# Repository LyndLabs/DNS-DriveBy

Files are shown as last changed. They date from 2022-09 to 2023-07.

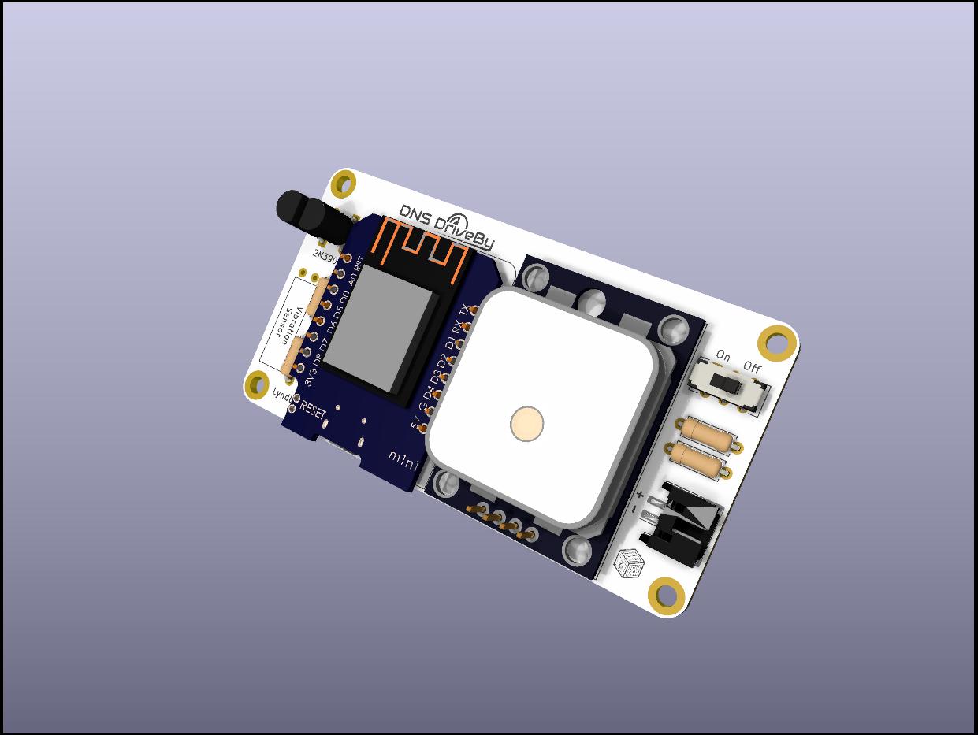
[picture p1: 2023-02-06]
images/DNS-DriveBy-Render.jpg

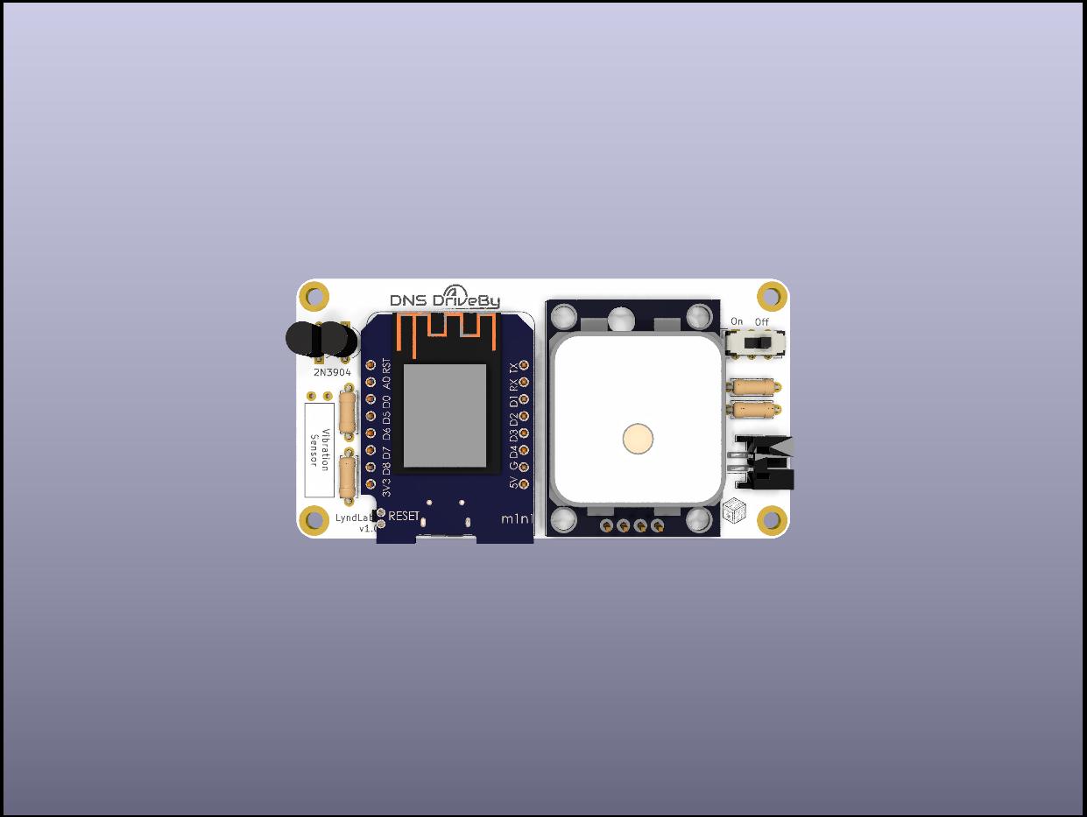
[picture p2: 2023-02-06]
images/DNS-DriveBy-Render-2.jpg

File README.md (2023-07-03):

<p align="center">

</p>

## What is DNS DriveBy?     
DNS-Driveby is a $10 tracker that uses Open Wi-Fi networks for telemetry & reconaissance, instead of a SIM card.  It logs GPS coordinates & other data to its internal memory, scans for un-authenticated Wi-Fi networks, and uses DNS Exfiltration through [DNS CanaryTokens](https://canarytokens.org) to bypass captive portals!  Read about how I created it on [Hackster](https://www.hackster.io/alexlynd/dns-driveby-stealthy-gps-tracking-using-open-wi-fi-65730a)!

## Resources
- Stealthy GPS Tracking Using Open Wi-Fi - [Hackster](https://www.hackster.io/alexlynd/dns-driveby-stealthy-gps-tracking-using-open-wi-fi-65730a)
- Using DNS DriveBy as a GPS Tracker - [Hak5](https://youtu.be/H0Nwff0KDJ0?t=151)

## Build Instructions
[Assembly Guide](https://dnsdriveby.com/guides/get-started/assembly/)

## Changelog v1.2
- MicroSD Card Support
- JST Switch connector?
- Route LiPo under board
- SH1106 / SSD1306 Add-On

## To-Do
- Fix GPS Traces
- Larger Resistor Footprint
- Improved BMS

- Screen Support
- Build Custom Binary
- OTA Update via Web Interface

## Documented Issues (Note to Self / Future Docs)
- Arduino-CLI VSCode Plugin doesn't support SPIFFS build

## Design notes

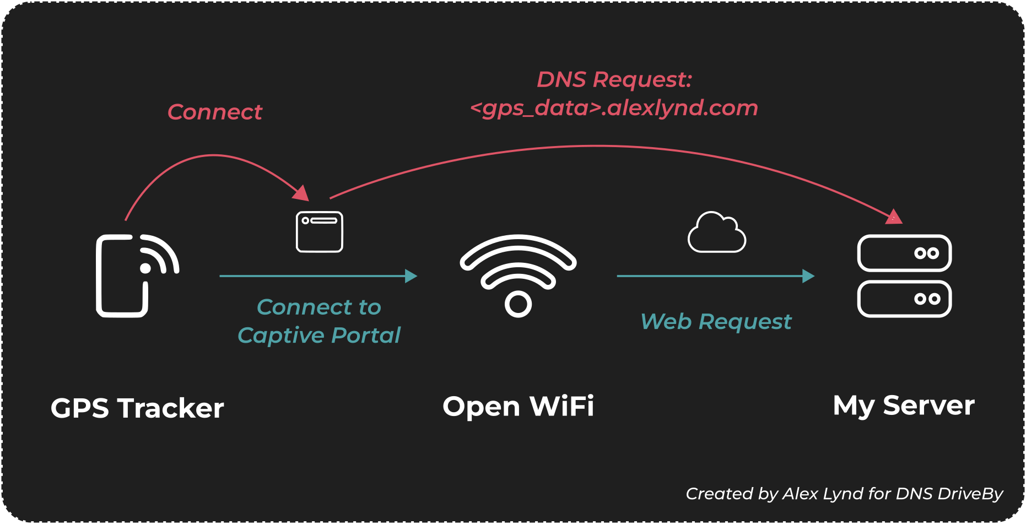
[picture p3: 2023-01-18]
images/dns-exfil-model.png

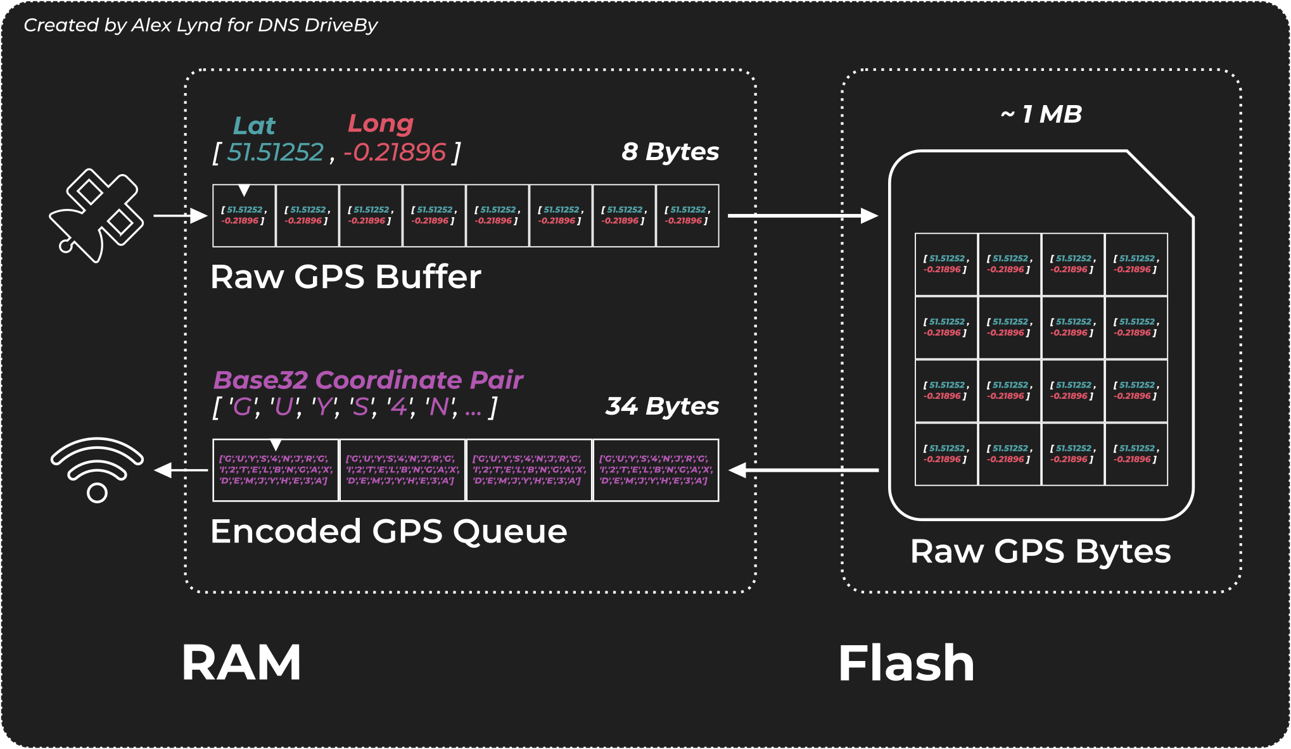
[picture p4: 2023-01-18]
images/memory-model.png

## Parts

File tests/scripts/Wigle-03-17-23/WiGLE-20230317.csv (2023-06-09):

WigleWifi-1.4 | appRelease=2.x | model=SERVER | release=2.50 | device=WiGLE SERVER | display=NONE | brand=WiGLE.net
MAC | SSID | AuthMode | FirstSeen | Channel | RSSI | CurrentLatitude | CurrentLongitude | AltitudeMeters | AccuracyMeters | Type
00:01:21:20:0B:40 |  | [WPA2-PSK-CCMP] | 2023-03-17 17:50:40 | -1 | -88 | 33.85910797 | -118.01226807 | -17 | 3.216 | WIFI
00:01:21:20:0B:41 | BBD Public | [WPA2-PSK-CCMP] | 2023-03-17 17:50:40 | -1 | -88 | 33.85910797 | -118.01226807 | -17 | 3.216 | WIFI
00:01:21:20:0B:42 | BBD Private | [WPA2-PSK-CCMP] | 2023-03-17 17:50:40 | -1 | -88 | 33.85910797 | -118.01226807 | -17 | 3.216 | WIFI
00:01:21:6D:9A:F0 |  | [WPA2-PSK-CCMP] | 2023-03-17 17:50:40 | -1 | -87 | 33.85910797 | -118.01226807 | -17 | 3.216 | WIFI
00:01:21:6D:9A:F1 | BBD Public | [WPA2-PSK-CCMP] | 2023-03-17 17:50:40 | -1 | -89 | 33.85910797 | -118.01226807 | -17 | 3.216 | WIFI
00:01:21:6D:9A:F2 | BBD Private | [WPA2-PSK-CCMP] | 2023-03-17 17:50:40 | -1 | -89 | 33.85910797 | -118.01226807 | -17 | 3.216 | WIFI
00:04:F3:1A:96:80 | xbee-0004F31A9680 | [WPA2-PSK-CCMP] | 2023-03-17 17:05:41 | -1 | -79 | 33.88780975 | -118.02951813 | -8 | 4.288 | WIFI
00:0A:99:8B:1F:3F | 336645 | [WPA-PSK-CCMP] | 2023-03-17 17:25:41 | -1 | -80 | 33.87351608 | -118.02902985 | -2 | 9.648 | WIFI
00:0D:97:01:14:AB | Standalone | [] | 2023-03-17 17:27:41 | -1 | -76 | 33.87284088 | -118.02864838 | -6 | 3.216 | WIFI
00:0E:3B:2C:6A:60 | Vaado | [WPA-PSK-CCMP] | 2023-03-17 17:56:12 | -1 | -81 | 33.85915756 | -118.0036087 | -26 | 9.648 | WIFI
00:11:32:E3:EC:1D | EKO | [WPA2-PSK-CCMP] | 2023-03-17 15:54:34 | -1 | -83 | 33.86017609 | -117.99799347 | 8 | 3.216 | WIFI
00:11:32:E7:2F:D0 | EKO | [WPA2-PSK-CCMP] | 2023-03-17 15:54:34 | -1 | -76 | 33.86017609 | -117.99799347 | 8 | 5.36 | WIFI
00:11:32:E7:37:CD | EKO | [WPA2-PSK-CCMP] | 2023-03-17 15:54:34 | -1 | -87 | 33.86017609 | -117.99799347 | 8 | 5.36 | WIFI
00:11:74:ED:C6:E0 |  | [WPA2-PSK-CCMP] | 2023-03-17 16:04:40 | -1 | -85 | 33.86976242 | -117.99803162 | -5 | 3.216 | WIFI
00:11:74:ED:C6:E1 |  | [WPA2-PSK-CCMP] | 2023-03-17 16:04:40 | -1 | -84 | 33.86976242 | -117.99803162 | -5 | 3.216 | WIFI
00:11:74:ED:C6:F0 |  | [WPA2-PSK-CCMP] | 2023-03-17 16:05:10 | -1 | -75 | 33.87014008 | -117.99806213 | -7 | 3.216 | WIFI
00:11:74:ED:C6:F1 |  | [WPA2-PSK-CCMP] | 2023-03-17 16:05:10 | -1 | -75 | 33.87014008 | -117.99806213 | -7 | 3.216 | WIFI
00:18:0A:23:FC:A4 | Ken Grody Ford- Guest | [WPA2-PSK-CCMP] | 2023-03-17 16:04:10 | -1 | -77 | 33.86975861 | -117.99802399 | -6 | 3.216 | WIFI
00:18:0A:F0:5A:C0 | OM | [WPA2-PSK-CCMP] | 2023-03-17 17:24:41 | -1 | -81 | 33.873806 | -118.02893829 | -2 | 9.648 | WIFI
00:18:0A:F1:74:50 | RFInternal | [WPA2-PSK-CCMP] | 2023-03-17 17:19:41 | -1 | -83 | 33.87769318 | -118.02895355 | -6 | 10.72 | WIFI
00:1E:F7:54:24:D3 | vendor_wifi | [WPA2-PSK-CCMP] | 2023-03-17 17:33:41 | -1 | -80 | 33.8686676 | -118.02858734 | -15 | 9.648 | WIFI
00:1F:26:2B:DA:20 |  | [WPA2-PSK-CCMP] | 2023-03-17 17:33:41 | -1 | -89 | 33.8686676 | -118.02858734 | -15 | 9.648 | WIFI
00:1F:26:2B:FC:40 |  | [WPA2-PSK-CCMP] | 2023-03-17 17:33:41 | -1 | -89 | 33.8686676 | -118.02858734 | -15 | 9.648 | WIFI
00:1F:26:2B:FC:43 | vendor_wifi | [WPA2-PSK-CCMP] | 2023-03-17 17:33:41 | -1 | -87 | 33.8686676 | -118.02858734 | -15 | 9.648 | WIFI
00:1F:26:2B:FC:49 |  | [WEP] | 2023-03-17 17:33:41 | -1 | -89 | 33.8686676 | -118.02858734 | -15 | 9.648 | WIFI
00:22:3B:0D:7B:B5 | Netwave-1 | [WPA2-PSK-CCMP] | 2023-03-17 16:15:10 | -1 | -87 | 33.87334061 | -118.00759125 | -7 | 3.216 | WIFI
00:25:CA:29:8D:8B | sdp5g | [WPA2-PSK-CCMP] | 2023-03-17 17:03:11 | -1 | -83 | 33.88780975 | -118.02951813 | -8 | 3.216 | WIFI
00:25:CA:6A:2C:F1 | KeepTruckin Hotspot - HB493614 | [WPA2-PSK-CCMP] | 2023-03-17 17:15:41 | -1 | -78 | 33.88343811 | -118.02910614 | 6 | 9.648 | WIFI
00:25:CA:6D:9B:7B | KeepTruckin Hotspot - HB514740 | [WPA2-PSK-CCMP] | 2023-03-17 17:36:41 | -1 | -85 | 33.8663826 | -118.02852631 | -16 | 9.648 | WIFI
00:30:44:2E:20:FD |  | [WPA2-PSK-CCMP] | 2023-03-17 16:04:10 | -1 | -79 | 33.86975861 | -117.99802399 | -6 | 3.216 | WIFI
00:30:44:62:91:D7 | KIMSBY HOUSE 2G | [WPA2-PSK-CCMP] | 2023-03-17 17:01:41 | -1 | -90 | 33.88779831 | -118.02951813 | -6 | 3.216 | WIFI
00:31:92:DA:F1:16 | TP-Link_F117 | [WPA2-PSK-CCMP] | 2023-03-17 17:31:41 | -1 | -88 | 33.87091064 | -118.02863312 | -11 | 3.216 | WIFI
00:31:92:DA:F1:17 | TP-Link_F117 | [WPA2-PSK-CCMP] | 2023-03-17 17:30:41 | -1 | -81 | 33.87123871 | -118.02864075 | -11 | 9.648 | WIFI
00:54:AF:14:75:8B | Hotspot758B | [WPA2-PSK-CCMP] | 2023-03-17 17:10:41 | -1 | -82 | 33.88757706 | -118.02933502 | -8 | 3.216 | WIFI
00:54:AF:1B:D0:05 | HotspotD005 | [WPA2-PSK-CCMP] | 2023-03-17 16:03:40 | -1 | -72 | 33.86941147 | -117.99812317 | 2 | 10.72 | WIFI
00:54:AF:27:BF:8D | HotspotBF8D | [WPA2-PSK-CCMP] | 2023-03-17 17:13:41 | -1 | -66 | 33.88420486 | -118.0291214 | 9 | 4.288 | WIFI
00:54:AF:2F:3F:3E | Hotspot3F3E | [WPA2-PSK-CCMP] | 2023-03-17 15:46:38 | -1 | -70 | 33.85936356 | -117.99797821 | 11 | 34.304 | WIFI
00:54:AF:3A:E8:64 | HotspotE864 | [WPA2-PSK-CCMP] | 2023-03-17 16:56:41 | -1 | -79 | 33.88788605 | -118.02905273 | -6 | 9.648 | WIFI
00:54:AF:7E:57:79 | Hotspot5779 | [WPA2-PSK-CCMP] | 2023-03-17 16:08:40 | -1 | -78 | 33.87332916 | -117.99813843 | -5 | 3.216 | WIFI
00:54:AF:D1:C8:B8 | HotspotC8B8 | [WPA2-PSK-CCMP] | 2023-03-17 16:58:12 | -1 | -91 | 33.88783264 | -118.02954865 | -8 | 9.648 | WIFI
00:54:AF:DB:7E:1C | Hotspot7E1C | [WPA2-PSK-CCMP] | 2023-03-17 17:24:41 | -1 | -72 | 33.873806 | -118.02893829 | -2 | 9.648 | WIFI
00:54:AF:E8:93:35 | Hotspot9335 | [WPA2-PSK-CCMP] | 2023-03-17 17:00:12 | -1 | -82 | 33.88781357 | -118.0295105 | -7 | 3.216 | WIFI
00:54:AF:E9:B6:CA | HotspotB6CA | [WPA2-PSK-CCMP] | 2023-03-17 17:02:11 | -1 | -83 | 33.88780975 | -118.02951813 | -8 | 3.216 | WIFI
00:54:AF:F5:75:0F | Hotspot750F | [WPA2-PSK-CCMP] | 2023-03-17 18:00:42 | -1 | -86 | 33.86008835 | -118.00170135 | -15 | 4.288 | WIFI
00:71:CC:32:A7:EB | HP-Print-EB-LaserJet 1102 | [] | 2023-03-17 15:54:10 | -1 | -70 | 33.8600502 | -117.99802399 | 9 | 4.288 | WIFI
00:80:AE:C0:83:81 | hug2g843283 | [WPA2-PSK-CCMP] | 2023-03-17 17:06:10 | -1 | -73 | 33.88780975 | -118.02951813 | -8 | 3.216 | WIFI
00:80:AE:C0:83:82 | hug5g843283 | [WPA2-PSK-CCMP] | 2023-03-17 17:06:10 | -1 | -87 | 33.88780975 | -118.02951813 | -8 | 3.216 | WIFI
00:AC:E0:92:1E:00 | KACS | [WPA2-PSK-CCMP] | 2023-03-17 17:46:11 | -1 | -72 | 33.85908127 | -118.02080536 | -24 | 9.648 | WIFI
00:AC:E0:92:1E:05 | KACS-5G | [WPA2-PSK-CCMP] | 2023-03-17 17:45:41 | -1 | -83 | 33.85906982 | -118.02161407 | -21 | 9.648 | WIFI
00:B7:71:46:A8:A0 | Employee | [] | 2023-03-17 16:23:40 | -1 | -86 | 33.87703323 | -118.01000977 | -8 | 9.648 | WIFI
00:C8:8B:9D:44:E2 |  | [WPA2-PSK-CCMP] | 2023-03-17 17:16:41 | -1 | -90 | 33.88157654 | -118.02909088 | 2 | 9.648 | WIFI
00:CB:51:41:14:36 | Minguela | [WPA2-PSK-CCMP] | 2023-03-17 15:56:40 | -1 | -91 | 33.86224365 | -117.99797058 | -3 | 3.216 | WIFI
02:17:C8:83:50:F3 | DIRECT-GnKM66F255 | [WPA2-PSK-CCMP] | 2023-03-17 15:52:09 | -1 | -68 | 33.85932922 | -117.99767303 | 17 | 3.216 | WIFI
02:18:1A:23:FC:A4 | Ken Grody Ford- Guest | [WPA2-PSK-CCMP] | 2023-03-17 16:04:10 | -1 | -88 | 33.86975861 | -117.99802399 | -6 | 3.216 | WIFI
02:18:1A:23:FF:1C | Ken Grody Ford- Guest | [WPA2-PSK-CCMP] | 2023-03-17 16:06:40 | -1 | -84 | 33.87178802 | -117.99810791 | -9 | 9.648 | WIFI
02:18:1A:F0:5A:C0 | OM | [WPA2-PSK-CCMP] | 2023-03-17 17:24:41 | -1 | -88 | 33.873806 | -118.02893829 | -2 | 9.648 | WIFI
02:19:5D:91:CE:74 | Spectrum Mobile | [WPA2-PSK-CCMP] | 2023-03-17 16:11:40 | -1 | -81 | 33.87336349 | -118.00218964 | -2 | 11.792 | WIFI
02:26:66:DE:DC:DD | HPN911a.C06C03 | [ESS] | 2023-03-17 17:19:11 | -1 | -77 | 33.87800598 | -118.02900696 | -8 | 9.648 | WIFI
02:27:A7:77:14:77 | HPCP1525-2169b2 | [ESS] | 2023-03-17 16:32:10 | -1 | -89 | 33.88090134 | -118.0109787 | -10 | 3.216 | WIFI
02:2F:AF:C6:BE:C0 | HP840AA9 | [ESS] | 2023-03-17 17:39:41 | -1 | -87 | 33.86225128 | -118.02850342 | -17 | 9.648 | WIFI
02:30:44:2E:20:FE |  | [WPA2-PSK-CCMP] | 2023-03-17 16:03:40 | -1 | -80 | 33.86941147 | -117.99812317 | 2 | 3.216 | WIFI
02:54:AF:EE:27:7D | Hotspot277D | [WPA2-PSK-CCMP] | 2023-03-17 16:09:10 | -1 | -83 | 33.87337494 | -117.99853516 | -6 | 3.216 | WIFI
02:54:AF:F9:F3:F3 | HotspotF3F3 | [WPA2-PSK-CCMP] | 2023-03-17 16:54:41 | -1 | -78 | 33.88793945 | -118.02724457 | -8 | 3.216 | WIFI
02:54:AF:FA:A2:9B | HotspotA29B | [WPA2-PSK-CCMP] | 2023-03-17 16:17:40 | -1 | -87 | 33.87404251 | -118.00849152 | -9 | 3.216 | WIFI
02:54:AF:FE:27:FE | Hotspot27FE | [WPA2-PSK-CCMP] | 2023-03-17 17:11:41 | -1 | -63 | 33.88598633 | -118.0291748 | -4 | 9.648 | WIFI
02:71:47:36:76:C7 |  | [WPA2-PSK-CCMP] | 2023-03-17 16:54:41 | -1 | -77 | 33.88793945 | -118.02724457 | -8 | 3.216 | WIFI
02:8D:DB:C4:28:5F | GC_IoT | [WPA2-PSK-CCMP] | 2023-03-17 17:17:11 | -1 | -84 | 33.88054657 | -118.02906036 | -9 | 9.648 | WIFI
02:BE:F5:01:5B:DA | tl6f45bc-EXT | [WPA2-PSK-CCMP] | 2023-03-17 17:18:11 | -1 | -86 | 33.87891769 | -118.02905273 | -4 | 9.648 | WIFI
02:BF:AF:6B:28:FC |  | [WPA2-PSK-CCMP] | 2023-03-17 17:49:41 | -1 | -81 | 33.85907745 | -118.01436615 | -14 | 9.648 | WIFI
02:EC:DA:32:82:F9 | beacon | [WPA2-PSK-CCMP] | 2023-03-17 16:31:10 | -1 | -87 | 33.88088608 | -118.01075745 | -7 | 3.216 | WIFI
02:EC:DA:32:88:5C | beacon | [WPA2-PSK-CCMP] | 2023-03-17 16:31:10 | -1 | -87 | 33.88088608 | -118.01075745 | -7 | 3.216 | WIFI
02:EC:DA:33:82:F9 | beacon | [WPA2-PSK-CCMP] | 2023-03-17 16:35:11 | -1 | -83 | 33.88097763 | -118.01140594 | -6 | 3.216 | WIFI
02:EC:DA:33:88:5C | beacon | [WPA2-PSK-CCMP] | 2023-03-17 16:33:10 | -1 | -88 | 33.88098145 | -118.01142883 | -8 | 3.216 | WIFI
02:EC:DA:B8:E1:14 | Catnip3 | [WPA2-PSK-CCMP] | 2023-03-17 17:22:41 | -1 | -89 | 33.87483597 | -118.02895355 | -1 | 9.648 | WIFI
04:18:D6:82:53:15 | UCC-BP | [WPA2-PSK-CCMP] | 2023-03-17 16:26:40 | -1 | -89 | 33.87857056 | -118.01000977 | -3 | 9.648 | WIFI
04:18:D6:C2:29:AF | DWW-IT-WiFi-Extender | [WPA2-PSK-CCMP] | 2023-03-17 16:58:12 | -1 | -86 | 33.88783264 | -118.02954865 | -8 | 9.648 | WIFI
04:42:1A:18:3F:A0 | Life4cuts | [WPA2-PSK-CCMP] | 2023-03-17 15:50:39 | -1 | -64 | 33.85932922 | -117.99767303 | 17 | 4.288 | WIFI
04:42:1A:18:3F:A4 | Life4cuts | [WPA2-PSK-CCMP] | 2023-03-17 15:46:38 | -1 | -84 | 33.85936356 | -117.99797821 | 11 | 34.304 | WIFI
04:42:1A:50:7A:3C | BJC_And_MMT_5G | [WPA2-PSK-CCMP] | 2023-03-17 16:12:10 | -1 | -70 | 33.87334442 | -118.00255585 | -9 | 9.648 | WIFI
04:95:E6:27:BD:71 | Uni & Good Friend | [WPA2-PSK-CCMP] | 2023-03-17 16:04:40 | -1 | -87 | 33.86976242 | -117.99803162 | -5 | 3.216 | WIFI
04:D5:90:F4:3C:D0 | afaci_it | [WPA2-PSK-CCMP] | 2023-03-17 16:49:10 | -1 | -89 | 33.88800049 | -118.0171814 | -7 | 3.216 | WIFI
04:D5:90:F4:3D:70 | afaci_it | [WPA2-PSK-CCMP] | 2023-03-17 16:49:10 | -1 | -74 | 33.88800049 | -118.0171814 | -7 | 3.216 | WIFI
04:D5:90:F4:3D:71 | employee_login | [WPA2-PSK-CCMP] | 2023-03-17 16:49:10 | -1 | -74 | 33.88800049 | -118.0171814 | -7 | 3.216 | WIFI
04:D5:90:F4:3D:78 | afaci_it | [WPA2-PSK-CCMP] | 2023-03-17 16:49:10 | -1 | -82 | 33.88800049 | -118.0171814 | -7 | 3.216 | WIFI
04:D5:90:F4:41:A9 | employee_login | [WPA2-PSK-CCMP] | 2023-03-17 16:48:40 | -1 | -84 | 33.88800812 | -118.01618195 | -5 | 3.216 | WIFI
04:D5:90:F4:4A:18 | afaci_it | [WPA2-PSK-CCMP] | 2023-03-17 16:49:10 | -1 | -73 | 33.88800049 | -118.0171814 | -7 | 3.216 | WIFI
04:D5:90:F4:4A:19 | employee_login | [WPA2-PSK-CCMP] | 2023-03-17 16:49:10 | -1 | -72 | 33.88800049 | -118.0171814 | -7 | 3.216 | WIFI
04:D5:90:F4:4C:E8 | afaci_it | [WPA2-PSK-CCMP] | 2023-03-17 16:46:40 | -1 | -72 | 33.88682556 | -118.01579285 | -1 | 10.72 | WIFI
04:D5:90:F4:4C:E9 | employee_login | [WPA2-PSK-CCMP] | 2023-03-17 16:46:40 | -1 | -72 | 33.88682556 | -118.01579285 | -1 | 10.72 | WIFI
04:D5:90:F4:4D:C0 | afaci_it | [WPA2-PSK-CCMP] | 2023-03-17 16:47:10 | -1 | -82 | 33.88751221 | -118.01581573 | 4 | 9.648 | WIFI
04:D5:90:F4:4D:C1 | employee_login | [WPA2-PSK-CCMP] | 2023-03-17 16:47:10 | -1 | -74 | 33.88751221 | -118.01581573 | 4 | 9.648 | WIFI
04:D5:90:F4:4D:C8 | afaci_it | [WPA2-PSK-CCMP] | 2023-03-17 16:46:40 | -1 | -89 | 33.88682556 | -118.01579285 | -1 | 10.72 | WIFI
04:D9:F5:74:0A:88 | GHAR | [WPA2-PSK-CCMP] | 2023-03-17 17:56:12 | -1 | -83 | 33.85915756 | -118.0036087 | -26 | 9.648 | WIFI
04:F0:21:2A:14:FB |  | [WPA2-PSK-CCMP] | 2023-03-17 16:17:40 | -1 | -79 | 33.87404251 | -118.00849152 | -9 | 3.216 | WIFI
04:F0:21:59:78:67 | Free Metro WiFi | [] | 2023-03-17 15:59:10 | -1 | -85 | 33.86362839 | -117.99773407 | -2 | 10.72 | WIFI
04:F0:21:83:D5:EE | Free Metro WiFi | [] | 2023-03-17 16:51:40 | -1 | -87 | 33.88796616 | -118.02188873 | -9 | 9.648 | WIFI
04:F0:21:A2:A1:F1 | C3-Credit | [WPA2-PSK-CCMP] | 2023-03-17 16:31:40 | -1 | -87 | 33.88088989 | -118.0109024 | -9 | 3.216 | WIFI
06:18:0A:23:FC:A4 | Ken Grody Ford- Staff | [WPA2-PSK-CCMP] | 2023-03-17 16:04:10 | -1 | -77 | 33.86975861 | -117.99802399 | -6 | 3.216 | WIFI
06:18:0A:7A:FC:BE |  | [WPA2-PSK-CCMP] | 2023-03-17 16:06:10 | -1 | -81 | 33.87127686 | -117.99811554 | -4 | 10.72 | WIFI
06:18:0A:F1:74:50 | RFGuest | [WPA2-PSK-CCMP] | 2023-03-17 17:19:41 | -1 | -85 | 33.87769318 | -118.02895355 | -6 | 10.72 | WIFI
06:18:1A:23:FC:A4 | Ken Grody Ford- Staff | [WPA2-PSK-CCMP] | 2023-03-17 16:04:10 | -1 | -88 | 33.86975861 | -117.99802399 | -6 | 3.216 | WIFI
06:18:1A:23:FF:1C | Ken Grody Ford- Staff | [WPA2-PSK-CCMP] | 2023-03-17 16:06:40 | -1 | -83 | 33.87178802 | -117.99810791 | -9 | 9.648 | WIFI
06:18:D6:C2:29:AF |  | [WPA2-PSK-CCMP] | 2023-03-17 16:56:41 | -1 | -87 | 33.88788605 | -118.02905273 | -6 | 9.648 | WIFI
06:8D:CB:6F:50:E9 | Interior2 | [WPA2-PSK-CCMP] | 2023-03-17 16:50:10 | -1 | -81 | 33.88799286 | -118.01957703 | -6 | 9.648 | WIFI
06:8D:CB:6F:52:35 | Interior2 | [WPA2-PSK-CCMP] | 2023-03-17 16:50:10 | -1 | -79 | 33.88799286 | -118.01957703 | -6 | 9.648 | WIFI
06:92:BF:54:91:06 | 126test | [WPA2-PSK-CCMP] | 2023-03-17 16:55:41 | -1 | -91 | 33.88782501 | -118.02885437 | -5 | 3.216 | WIFI
06:93:97:71:45:93 | payrollmaster-5G | [WPA2-PSK-CCMP] | 2023-03-17 17:42:41 | -1 | -89 | 33.85900879 | -118.0271759 | -18 | 9.648 | WIFI
06:EA:C9:DA:8F:F3 | ATTeUp7f5S | [WPA2-PSK-CCMP] | 2023-03-17 16:03:10 | -1 | -56 | 33.86873627 | -117.99803925 | -3 | 5.36 | WIFI
06:EC:DA:32:82:F9 | TS | [WPA2-PSK-CCMP] | 2023-03-17 16:33:10 | -1 | -79 | 33.88098145 | -118.01142883 | -8 | 3.216 | WIFI
06:EC:DA:32:88:5C | TS | [WPA2-PSK-CCMP] | 2023-03-17 16:31:40 | -1 | -92 | 33.88088989 | -118.0109024 | -9 | 3.216 | WIFI
06:EC:DA:33:82:F9 | TS | [WPA2-PSK-CCMP] | 2023-03-17 16:33:10 | -1 | -87 | 33.88098145 | -118.01142883 | -8 | 3.216 | WIFI
06:EC:DA:33:88:5C | TS | [WPA2-PSK-CCMP] | 2023-03-17 16:32:10 | -1 | -89 | 33.88090134 | -118.0109787 | -10 | 3.216 | WIFI
06:EC:DA:B8:E1:14 | FLXPRIME3 | [WPA2-PSK-CCMP] | 2023-03-17 17:22:41 | -1 | -89 | 33.87483597 | -118.02895355 | -1 | 9.648 | WIFI
08:36:C9:86:3F:87 | PERMAGRO | [WPA2-PSK-CCMP] | 2023-03-17 17:53:42 | -1 | -77 | 33.8591156 | -118.00852966 | -21 | 3.216 | WIFI
08:36:C9:86:3F:88 |  | [WPA2-PSK-CCMP] | 2023-03-17 17:53:42 | -1 | -80 | 33.8591156 | -118.00852966 | -21 | 3.216 | WIFI
08:36:C9:E2:6A:7C | MySpectrumWiFif8-5G | [WPA2-PSK-CCMP] | 2023-03-17 17:14:41 | -1 | -88 | 33.88376617 | -118.02907562 | 7 | 3.216 | WIFI
08:36:C9:E2:6A:7E | MySpectrumWiFif8-2G | [WPA2-PSK-CCMP] | 2023-03-17 17:14:11 | -1 | -86 | 33.88381195 | -118.02910614 | 7 | 4.288 | WIFI
08:3E:5D:D6:1D:80 | Leaders WIFI 2G | [WPA2-PSK-CCMP] | 2023-03-17 17:51:12 | -1 | -79 | 33.8590889 | -118.01174927 | -17 | 3.216 | WIFI
08:3E:8E:43:6B:F7 | HP-Print-F7-LaserJet 1102 | [] | 2023-03-17 17:47:11 | -1 | -85 | 33.85907745 | -118.01899719 | -17 | 9.648 | WIFI
08:9B:B9:08:65:54 | ATTWFhj9u6 | [WPA2-PSK-CCMP] | 2023-03-17 16:03:40 | -1 | -50 | 33.86941147 | -117.99812317 | 2 | 10.72 | WIFI
08:9B:B9:08:65:58 | ATTWFhj9u6 | [WPA2-PSK-CCMP] | 2023-03-17 16:03:40 | -1 | -63 | 33.86941147 | -117.99812317 | 2 | 10.72 | WIFI
08:9B:B9:08:65:5C | ATTWFhj9u6 | [WPA2-PSK-CCMP] | 2023-03-17 16:03:40 | -1 | -75 | 33.86941147 | -117.99812317 | 2 | 10.72 | WIFI
08:9B:B9:08:6F:34 | YesGraphic-2G | [WPA2-PSK-CCMP] | 2023-03-17 17:51:12 | -1 | -83 | 33.8590889 | -118.01174927 | -17 | 3.216 | WIFI
08:9B:B9:08:6F:35 | ATT2hwn89I_Guest | [WPA2-PSK-CCMP] | 2023-03-17 17:51:12 | -1 | -82 | 33.8590889 | -118.01174927 | -17 | 3.216 | WIFI
08:9B:B9:08:6F:3C | YesGraphic-2G | [WPA2-PSK-CCMP] | 2023-03-17 17:53:12 | -1 | -86 | 33.85912323 | -118.0094986 | -17 | 3.216 | WIFI
08:9B:B9:08:91:A4 | Songhyun | [WPA2-PSK-CCMP] | 2023-03-17 16:04:40 | -1 | -76 | 33.86976242 | -117.99803162 | -5 | 3.216 | WIFI
08:9B:B9:08:91:A5 | ATTsxqXFzi_Guest | [WPA2-PSK-CCMP] | 2023-03-17 16:04:10 | -1 | -83 | 33.86975861 | -117.99802399 | -6 | 3.216 | WIFI
08:9B:B9:3D:C2:B4 | ATTaNDG5Rn | [WPA2-PSK-CCMP] | 2023-03-17 16:16:40 | -1 | -79 | 33.87334061 | -118.00762177 | -11 | 3.216 | WIFI
08:9B:B9:3E:52:6C | ATTIeKjbEy | [WPA2-PSK-CCMP] | 2023-03-17 16:02:10 | -1 | -80 | 33.86730957 | -117.99797058 | -10 | 3.216 | WIFI
08:9B:B9:47:AB:E4 | ATTDypc3aA | [WPA2-PSK-CCMP] | 2023-03-17 17:41:41 | -1 | -86 | 33.85920334 | -118.02848053 | -18 | 9.648 | WIFI
08:9B:B9:47:AB:E8 | ATTDypc3aA | [WPA2-PSK-CCMP] | 2023-03-17 17:41:41 | -1 | -86 | 33.85920334 | -118.02848053 | -18 | 9.648 | WIFI
08:B4:B1:07:D1:0A | shiptis | [WPA2-PSK-CCMP] | 2023-03-17 17:40:41 | -1 | -87 | 33.86066437 | -118.02848816 | -15 | 9.648 | WIFI
08:B4:B1:08:B4:C6 | shiptis | [WPA2-PSK-CCMP] | 2023-03-17 17:40:11 | -1 | -85 | 33.86140442 | -118.02848816 | -16 | 9.648 | WIFI
08:D5:9D:00:72:77 | San Sam Won33-5G | [WPA2-PSK-CCMP] | 2023-03-17 17:55:12 | -1 | -87 | 33.85912323 | -118.00550842 | -20 | 9.648 | WIFI
0A:19:5D:97:D4:E6 | Spectrum Mobile | [WPA2-PSK-CCMP] | 2023-03-17 17:48:11 | -1 | -72 | 33.85910034 | -118.01673889 | -23 | 9.648 | WIFI
0A:56:EE:56:95:EF |  | [WPA2-PSK-CCMP] | 2023-03-17 16:16:10 | -1 | -77 | 33.87334061 | -118.00762177 | -11 | 3.216 | WIFI
0A:56:EE:56:95:F6 |  | [WPA2-PSK-CCMP] | 2023-03-17 16:14:41 | -1 | -78 | 33.87332916 | -118.00670624 | -7 | 3.216 | WIFI
0A:56:EE:56:97:9F |  | [WPA2-PSK-CCMP] | 2023-03-17 16:14:41 | -1 | -87 | 33.87332916 | -118.00670624 | -7 | 3.216 | WIFI
0A:56:EE:78:51:26 |  | [WPA2-PSK-CCMP] | 2023-03-17 17:16:41 | -1 | -89 | 33.88157654 | -118.02909088 | 2 | 9.648 | WIFI
0A:80:AE:C0:83:81 |  | [WPA2-PSK-CCMP] | 2023-03-17 16:58:42 | -1 | -82 | 33.88781357 | -118.0295105 | -7 | 3.216 | WIFI
0A:80:AE:C0:83:82 |  | [WPA2-PSK-CCMP] | 2023-03-17 17:06:10 | -1 | -88 | 33.88780975 | -118.02951813 | -8 | 3.216 | WIFI
0A:8D:CB:6F:50:E9 | ILG-Guest | [] | 2023-03-17 16:50:10 | -1 | -81 | 33.88799286 | -118.01957703 | -6 | 9.648 | WIFI
0A:8D:CB:6F:52:35 | ILG-Guest | [] | 2023-03-17 16:50:10 | -1 | -79 | 33.88799286 | -118.01957703 | -6 | 9.648 | WIFI
0A:8D:CB:71:12:88 | Premier Guest | [] | 2023-03-17 16:16:10 | -1 | -85 | 33.87334061 | -118.00762177 | -11 | 3.216 | WIFI
0A:8D:DB:6F:50:E9 | ILG-Guest | [] | 2023-03-17 16:50:41 | -1 | -77 | 33.88800049 | -118.01992798 | -6 | 9.648 | WIFI
0A:8D:DB:6F:52:35 | ILG-Guest | [] | 2023-03-17 16:50:41 | -1 | -72 | 33.88800049 | -118.01992798 | -6 | 9.648 | WIFI
0A:EC:DA:32:82:F9 | TS | [WPA2-PSK-CCMP] | 2023-03-17 16:30:40 | -1 | -91 | 33.88074112 | -118.0105896 | -5 | 3.216 | WIFI
0A:EC:DA:32:86:1A | TS | [WPA2-PSK-CCMP] | 2023-03-17 16:31:10 | -1 | -91 | 33.88088608 | -118.01075745 | -7 | 9.648 | WIFI
0A:EC:DA:32:88:5C | TS | [WPA2-PSK-CCMP] | 2023-03-17 16:32:10 | -1 | -80 | 33.88090134 | -118.0109787 | -10 | 3.216 | WIFI
0A:EC:DA:33:82:F9 | TS | [WPA2-PSK-CCMP] | 2023-03-17 16:33:10 | -1 | -87 | 33.88098145 | -118.01142883 | -8 | 3.216 | WIFI
0A:EC:DA:33:88:5C | TS | [WPA2-PSK-CCMP] | 2023-03-17 16:35:11 | -1 | -84 | 33.88097763 | -118.01140594 | -6 | 3.216 | WIFI
0A:EC:DA:B8:E1:14 | FLXDOCK3 | [WPA2-PSK-CCMP] | 2023-03-17 17:22:41 | -1 | -89 | 33.87483597 | -118.02895355 | -1 | 9.648 | WIFI
0A:EC:DA:D4:5F:B5 | FLXDOCK3 | [WPA2-PSK-CCMP] | 2023-03-17 17:22:11 | -1 | -87 | 33.87518692 | -118.02896881 | -4 | 9.648 | WIFI
0C:68:03:5E:5D:81 |  | [WPA2-PSK-CCMP] | 2023-03-17 17:30:41 | -1 | -79 | 33.87123871 | -118.02864075 | -11 | 9.648 | WIFI
0C:68:03:5E:5D:83 |  | [WPA2-PSK-CCMP] | 2023-03-17 17:30:41 | -1 | -77 | 33.87123871 | -118.02864075 | -11 | 9.648 | WIFI
0C:7C:28:48:26:E8 | TMOBILE-26DD | [WPA2-PSK-CCMP] | 2023-03-17 17:53:42 | -1 | -89 | 33.8591156 | -118.00852966 | -21 | 3.216 | WIFI
0C:7C:28:A8:0E:9C | ATTrEYz7VB | [WPA2-PSK-CCMP] | 2023-03-17 17:55:12 | -1 | -76 | 33.85912323 | -118.00550842 | -20 | 9.648 | WIFI
0C:80:63:CD:36:FA | TP-Link_36FA | [WPA2-PSK-CCMP] | 2023-03-17 15:49:09 | -1 | -80 | 33.85932541 | -117.99765778 | 21 | 3.216 | WIFI
0C:80:63:F0:FC:79 | TP-Link_FC7A_5G | [WPA2-PSK-CCMP] | 2023-03-17 17:56:42 | -1 | -88 | 33.8591423 | -118.00312805 | -21 | 9.648 | WIFI
0C:80:63:F0:FC:7A | TP-Link_FC7A | [WPA2-PSK-CCMP] | 2023-03-17 17:56:42 | -1 | -75 | 33.8591423 | -118.00312805 | -21 | 9.648 | WIFI
0C:8D:DB:6F:4F:A7 | Interior | [WPA2-PSK-CCMP] | 2023-03-17 16:50:41 | -1 | -77 | 33.88800049 | -118.01992798 | -6 | 9.648 | WIFI
0C:8D:DB:6F:50:E9 | Interior | [WPA2-PSK-CCMP] | 2023-03-17 16:50:10 | -1 | -71 | 33.88799286 | -118.01957703 | -6 | 9.648 | WIFI
0C:AE:7D:4C:0C:62 | Ottogi 2nd Floor Lutron Hub | [WPA2-PSK-CCMP] | 2023-03-17 16:44:40 | -1 | -85 | 33.88504028 | -118.01583862 | 11 | 9.648 | WIFI
0C:AE:7D:4C:72:E0 | Ottogi 1st Floor Lutron Hub | [WPA2-PSK-CCMP] | 2023-03-17 16:44:40 | -1 | -84 | 33.88504028 | -118.01583862 | 11 | 9.648 | WIFI
0C:EA:C9:DA:8F:F0 | ATTeUp7f5S | [WPA2-PSK-CCMP] | 2023-03-17 16:03:10 | -1 | -60 | 33.86873627 | -117.99803925 | -3 | 5.36 | WIFI
0C:EA:C9:DA:8F:F3 |  | [WPA2-PSK-CCMP] | 2023-03-17 16:03:10 | -1 | -60 | 33.86873627 | -117.99803925 | -3 | 5.36 | WIFI
0E:19:5D:56:EE:A7 | Spectrum Mobile | [WPA2-PSK-CCMP] | 2023-03-17 16:07:10 | -1 | -84 | 33.87242126 | -117.99811554 | -7 | 9.648 | WIFI
0E:8D:9B:DF:BA:91 | MVP-West Employee | [WPA2-PSK-CCMP] | 2023-03-17 16:56:41 | -1 | -87 | 33.88788605 | -118.02905273 | -6 | 9.648 | WIFI
0E:8D:CB:6F:50:E9 | Interior | [WPA2-PSK-CCMP] | 2023-03-17 16:50:10 | -1 | -82 | 33.88799286 | -118.01957703 | -6 | 9.648 | WIFI
0E:8D:CB:6F:52:35 | Interior | [WPA2-PSK-CCMP] | 2023-03-17 16:50:10 | -1 | -79 | 33.88799286 | -118.01957703 | -6 | 9.648 | WIFI
0E:8D:CB:71:12:88 | Premier Wifi | [WPA2-PSK-CCMP] | 2023-03-17 16:16:10 | -1 | -85 | 33.87334061 | -118.00762177 | -11 | 3.216 | WIFI
0E:96:E6:A4:6B:56 | DIRECT-56-HP M477 LaserJet | [WPA2-PSK-CCMP] | 2023-03-17 16:52:41 | -1 | -84 | 33.88795853 | -118.02316284 | -10 | 10.72 | WIFI
0E:EC:DA:32:82:F9 |  | [WPA2-PSK-CCMP] | 2023-03-17 16:31:10 | -1 | -87 | 33.88088608 | -118.01075745 | -7 | 9.648 | WIFI
0E:EC:DA:32:88:5C |  | [WPA2-PSK-CCMP] | 2023-03-17 16:32:40 | -1 | -85 | 33.88092422 | -118.01125336 | -6 | 3.216 | WIFI
0E:EC:DA:33:82:F9 |  | [WPA2-PSK-CCMP] | 2023-03-17 16:33:10 | -1 | -87 | 33.88098145 | -118.01142883 | -8 | 3.216 | WIFI
0E:EC:DA:33:88:5C |  | [WPA2-PSK-CCMP] | 2023-03-17 16:32:10 | -1 | -89 | 33.88090134 | -118.0109787 | -10 | 3.216 | WIFI
0E:EC:DA:B8:E1:14 |  | [WPA2-PSK-CCMP] | 2023-03-17 17:22:41 | -1 | -88 | 33.87483597 | -118.02895355 | -1 | 9.648 | WIFI
10:0C:6B:26:DD:81 | NETGEAR72-5G | [WPA2-PSK-CCMP] | 2023-03-17 15:47:09 | -1 | -73 | 33.85932922 | -117.99767303 | 20 | 5.36 | WIFI
10:0C:6B:26:DD:82 | NETGEAR72 | [WPA2-PSK-CCMP] | 2023-03-17 15:47:09 | -1 | -58 | 33.85932922 | -117.99767303 | 20 | 5.36 | WIFI
10:0C:6B:50:D9:55 | LMES-5G | [WPA2-PSK-CCMP] | 2023-03-17 17:13:11 | -1 | -88 | 33.88506317 | -118.02915192 | 2 | 7.504 | WIFI
10:0C:6B:50:D9:56 | LMES | [WPA2-PSK-CCMP] | 2023-03-17 17:14:41 | -1 | -87 | 33.88376617 | -118.02907562 | 7 | 3.216 | WIFI
10:0C:6B:A0:78:F0 | Gravity | [WPA2-PSK-CCMP] | 2023-03-17 15:47:09 | -1 | -64 | 33.85932922 | -117.99767303 | 20 | 5.36 | WIFI
10:0C:6B:A0:78:F2 | Gravity-5G | [WPA2-PSK-CCMP] | 2023-03-17 15:49:09 | -1 | -63 | 33.85932541 | -117.99765778 | 21 | 3.216 | WIFI
10:2C:6B:18:67:E6 | SC200-EA7A20H04601 | [WPA2-PSK-CCMP] | 2023-03-17 17:13:11 | -1 | -82 | 33.88506317 | -118.02915192 | 2 | 7.504 | WIFI
10:2C:6B:D4:D4:8C | SC201-EA6A21H02978 | [WPA2-PSK-CCMP] | 2023-03-17 17:17:41 | -1 | -84 | 33.87948227 | -118.02907562 | -4 | 10.72 | WIFI
10:93:97:71:45:80 | ATTjnb68DS | [WPA2-PSK-CCMP] | 2023-03-17 16:03:40 | -1 | -85 | 33.86941147 | -117.99812317 | 2 | 10.72 | WIFI
10:93:97:71:45:90 | payrollmaster | [WPA2-PSK-CCMP] | 2023-03-17 17:42:41 | -1 | -77 | 33.85900879 | -118.0271759 | -18 | 9.648 | WIFI
10:93:97:71:45:93 |  | [WPA2-PSK-CCMP] | 2023-03-17 17:42:41 | -1 | -88 | 33.85900879 | -118.0271759 | -18 | 9.648 | WIFI
10:D7:B0:E3:56:8E | SANCHEZ5775 | [WPA2-PSK-CCMP] | 2023-03-17 15:58:40 | -1 | -73 | 33.86309052 | -117.99798584 | -4 | 10.72 | WIFI
10:DA:43:D2:D7:02 | NETGEAR10 | [WPA2-PSK-CCMP] | 2023-03-17 16:25:10 | -1 | -83 | 33.87791824 | -118.01000214 | -11 | 3.216 | WIFI
12:13:31:C0:8B:BD | Verizon-MBHA10-8BB5 | [WPA2-PSK-CCMP] | 2023-03-17 15:46:38 | -1 | -87 | 33.85936356 | -117.99797821 | 11 | 34.304 | WIFI
12:13:31:C0:8B:BE | Verizon-MBHA10-8BB5-guest | [WPA2-PSK-CCMP] | 2023-03-17 15:46:38 | -1 | -86 | 33.85936356 | -117.99797821 | 11 | 34.304 | WIFI
12:31:92:DA:F1:16 |  | [WPA2-PSK-CCMP] | 2023-03-17 17:31:41 | -1 | -90 | 33.87091064 | -118.02863312 | -11 | 3.216 | WIFI
12:31:92:DA:F1:17 |  | [WPA2-PSK-CCMP] | 2023-03-17 17:32:41 | -1 | -82 | 33.86974335 | -118.02827454 | -12 | 9.648 | WIFI
12:3D:0A:DD:48:FF |  | [WPA2-PSK-CCMP] | 2023-03-17 17:37:11 | -1 | -85 | 33.86592484 | -118.02856445 | -12 | 9.648 | WIFI
12:53:D2:CE:77:98 | Spectrum Mobile | [WPA2-PSK-CCMP] | 2023-03-17 16:13:40 | -1 | -87 | 33.87334824 | -118.00492859 | -11 | 9.648 | WIFI
12:E8:A7:0B:4B:E6 | myChevrolet 4be6 | [WPA2-PSK-CCMP] | 2023-03-17 15:54:40 | -1 | -88 | 33.8603096 | -117.99796295 | 2 | 3.216 | WIFI
12:E8:A7:28:E2:94 | Liberg wifi | [WPA2-PSK-CCMP] | 2023-03-17 17:13:41 | -1 | -85 | 33.88420486 | -118.0291214 | 9 | 4.288 | WIFI
12:E8:A7:38:E2:94 | Liberg wifi | [WPA2-PSK-CCMP] | 2023-03-17 17:13:41 | -1 | -74 | 33.88420486 | -118.0291214 | 9 | 4.288 | WIFI
12:E8:A7:40:64:3E | DIRECT-MBUX 28245 | [WPA2-PSK-CCMP] | 2023-03-17 16:12:40 | -1 | -87 | 33.87335205 | -118.00317383 | -7 | 10.72 | WIFI
12:E8:A7:CF:8F:3B | MBUX 58215 | [WPA2-PSK-CCMP] | 2023-03-17 17:51:12 | -1 | -84 | 33.8590889 | -118.01174927 | -17 | 3.216 | WIFI
12:E8:A7:EA:B4:E1 | Hannah | [WPA2-PSK-CCMP] | 2023-03-17 17:00:12 | -1 | -89 | 33.88781357 | -118.0295105 | -7 | 3.216 | WIFI
14:22:3B:0F:8D:42 | AB Nest | [WPA2-PSK-CCMP] | 2023-03-17 16:22:11 | -1 | -92 | 33.87620163 | -118.0100174 | -10 | 9.648 | WIFI
14:3F:C3:44:62:AE | GOC Artesia | [WPA2-PSK-CCMP] | 2023-03-17 16:14:10 | -1 | -79 | 33.87334824 | -118.00583649 | -5 | 9.648 | WIFI
14:42:FC:FA:D5:76 | PNet6745009 | [WPA2-PSK-CCMP] | 2023-03-17 17:03:11 | -1 | -81 | 33.88780975 | -118.02951813 | -8 | 3.216 | WIFI
14:58:D0:2C:D8:14 | EPS WiFi | [WPA2-PSK-CCMP] | 2023-03-17 17:49:41 | -1 | -89 | 33.85907745 | -118.01436615 | -14 | 9.648 | WIFI
14:59:C0:4F:F3:27 | #patron# | [WPA2-PSK-CCMP] | 2023-03-17 17:44:11 | -1 | -83 | 33.85905075 | -118.02412415 | -17 | 9.648 | WIFI
14:59:C0:BA:96:30 | donmelt | [WPA2-PSK-CCMP] | 2023-03-17 15:47:09 | -1 | -66 | 33.85932922 | -117.99767303 | 20 | 5.36 | WIFI
14:59:C0:BA:96:32 | donmelt-5G | [WPA2-PSK-CCMP] | 2023-03-17 15:47:09 | -1 | -84 | 33.85932922 | -117.99767303 | 20 | 5.36 | WIFI
14:59:C0:BD:03:04 | NETGEAR35-5G | [WPA2-PSK-CCMP] | 2023-03-17 15:46:38 | -1 | -83 | 33.85936356 | -117.99797821 | 11 | 34.304 | WIFI
14:59:C0:BF:3B:BE | Nationwide | [WPA2-PSK-CCMP] | 2023-03-17 17:41:41 | -1 | -77 | 33.85920334 | -118.02848053 | -18 | 9.648 | WIFI
14:59:C0:BF:3B:C0 |  | [WPA2-PSK-CCMP] | 2023-03-17 17:42:11 | -1 | -87 | 33.85898972 | -118.02824402 | -16 | 9.648 | WIFI
14:77:40:F9:6D:34 | Prinebayinc666 | [WPA2-PSK-CCMP] | 2023-03-17 17:32:41 | -1 | -76 | 33.86974335 | -118.02827454 | -12 | 9.648 | WIFI
14:77:40:F9:6D:38 | Prinebayinc666 | [WPA2-PSK-CCMP] | 2023-03-17 17:32:11 | -1 | -78 | 33.87011337 | -118.02838135 | -12 | 5.36 | WIFI
14:77:40:F9:6D:39 |  | [WPA2-PSK-CCMP] | 2023-03-17 17:32:11 | -1 | -67 | 33.87011337 | -118.02838135 | -12 | 5.36 | WIFI
14:77:40:F9:6D:3A |  | [WPA2-PSK-CCMP] | 2023-03-17 17:32:11 | -1 | -79 | 33.87011337 | -118.02838135 | -12 | 5.36 | WIFI
14:7D:05:8F:48:0B | SpectrumSetup-09 | [WPA2-PSK-CCMP] | 2023-03-17 16:09:40 | -1 | -87 | 33.8734169 | -117.99936676 | -11 | 9.648 | WIFI
14:7D:05:E8:F4:46 | SpectrumSetup-45 | [WPA2-PSK-CCMP] | 2023-03-17 16:12:40 | -1 | -72 | 33.87335205 | -118.00317383 | -7 | 10.72 | WIFI
14:7D:05:E8:F4:47 | SpectrumSetup-45 | [WPA2-PSK-CCMP] | 2023-03-17 16:12:40 | -1 | -56 | 33.87335205 | -118.00317383 | -7 | 10.72 | WIFI
14:91:82:12:9F:32 | ChapletTours.media | [WPA2-PSK-CCMP] | 2023-03-17 17:46:41 | -1 | -84 | 33.85905075 | -118.0200882 | -22 | 10.72 | WIFI
14:EB:B6:76:F3:92 | JP CrownHouse | [WPA2-PSK-CCMP] | 2023-03-17 17:46:11 | -1 | -75 | 33.85908127 | -118.02080536 | -24 | 9.648 | WIFI
14:EB:B6:76:F3:93 | JP CrownHouse | [WPA2-PSK-CCMP] | 2023-03-17 17:45:41 | -1 | -86 | 33.85906982 | -118.02161407 | -21 | 9.648 | WIFI
14:ED:BB:8A:B5:5A | Robinson30 | [WPA2-PSK-CCMP] | 2023-03-17 16:11:10 | -1 | -88 | 33.8733902 | -118.00189209 | -10 | 9.648 | WIFI
14:ED:BB:C7:EE:4D | ATT3HCe2aS | [WPA2-PSK-CCMP] | 2023-03-17 16:13:10 | -1 | -77 | 33.87336349 | -118.00387573 | -8 | 9.648 | WIFI
14:ED:BB:C7:EE:56 | ATT3HCe2aS | [WPA2-PSK-CCMP] | 2023-03-17 16:13:40 | -1 | -82 | 33.87334824 | -118.00492859 | -11 | 9.648 | WIFI
16:11:32:E3:EC:1D |  | [WPA2-PSK-CCMP] | 2023-03-17 15:54:34 | -1 | -84 | 33.86017609 | -117.99799347 | 8 | 5.36 | WIFI
16:11:32:E7:2F:CE |  | [WPA2-PSK-CCMP] | 2023-03-17 15:54:10 | -1 | -76 | 33.8600502 | -117.99802399 | 9 | 4.288 | WIFI
16:11:32:E7:2F:CF |  | [WPA2-PSK-CCMP] | 2023-03-17 15:54:34 | -1 | -80 | 33.86017609 | -117.99799347 | 8 | 5.36 | WIFI
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

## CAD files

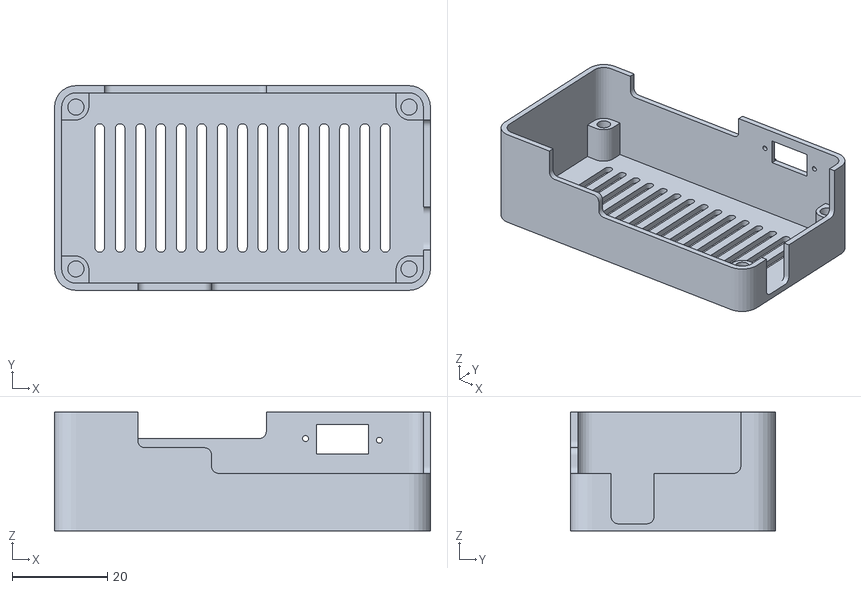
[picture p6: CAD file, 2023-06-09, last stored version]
hardware/Enclosure-DNS-DriveBy/DNS-Driveby-Skeleton-v1.1.stl
79.0 x 43.0 x 25.0

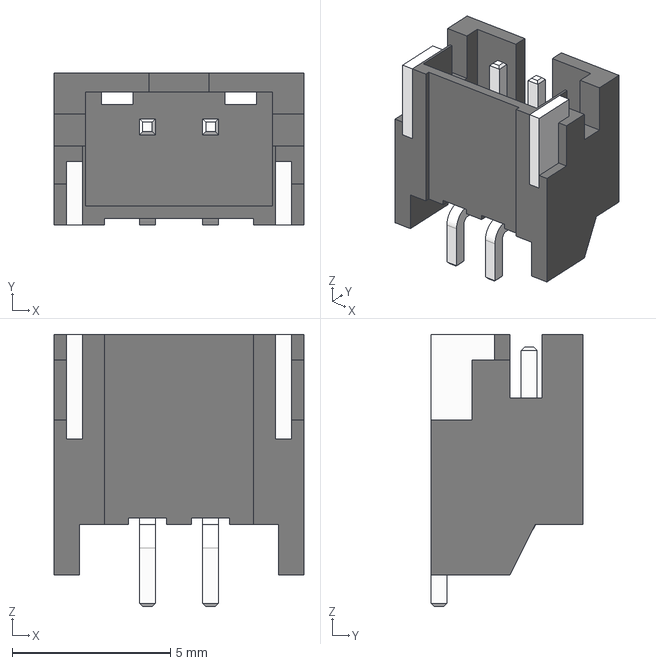
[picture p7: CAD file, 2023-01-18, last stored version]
hardware/PCB-DNS-DriveBy/DNS-DriveBy/3d-models/JST-PH-2 v1.step
7.90 x 4.80 x 8.60 mm

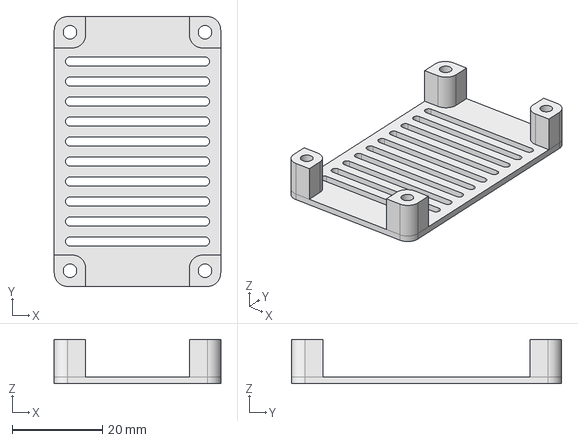
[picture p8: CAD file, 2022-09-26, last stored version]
Lid.FCStd
37.0 x 60.0 x 9.80 mm

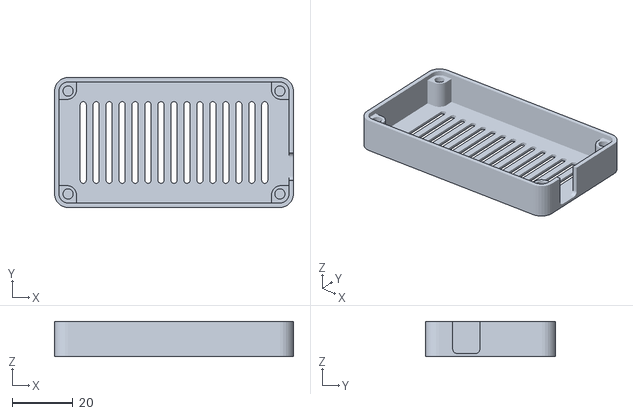
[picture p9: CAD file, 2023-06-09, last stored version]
hardware/Enclosure-DNS-DriveBy/DNS-Driveby-Slim-v1.0.stl
79.0 x 43.0 x 11.6

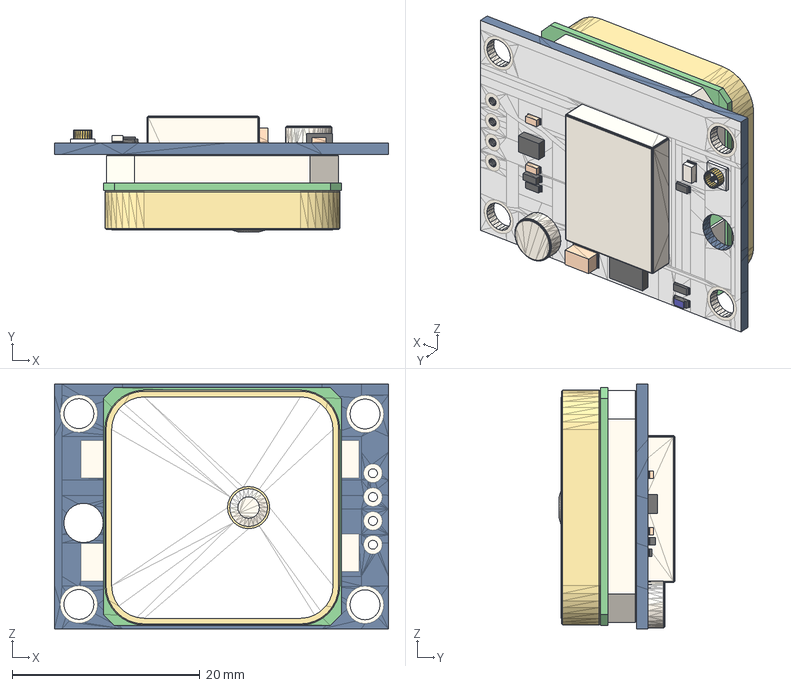
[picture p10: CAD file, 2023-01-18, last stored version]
hardware/PCB-DNS-DriveBy/DNS-DriveBy/3d-models/NEO-6M-GPS.step
35.6 x 12.3 x 26.1 mm
GPS_ublox_board-1
GPS_board-1
GPS_ant-1
GPS_back-1

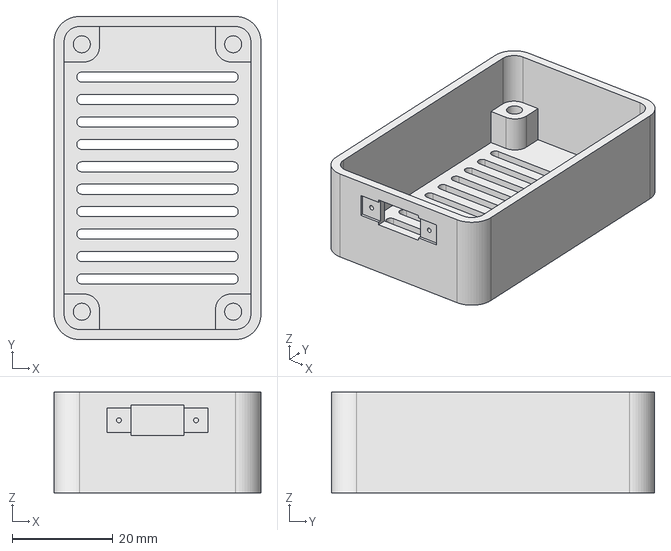
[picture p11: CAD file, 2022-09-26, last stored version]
Enclosure.FCStd
41.0 x 64.0 x 20.0 mm

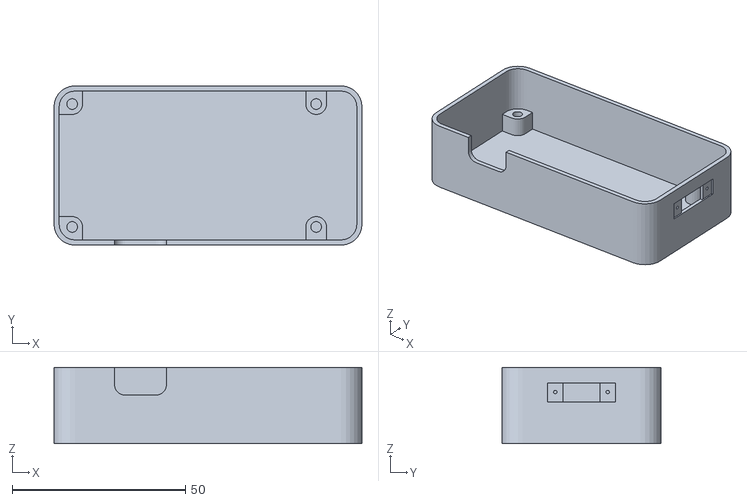
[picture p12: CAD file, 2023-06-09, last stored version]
hardware/Enclosure-DNS-DriveBy/PCB-Enclosure.stl
89.0 x 46.0 x 22.0

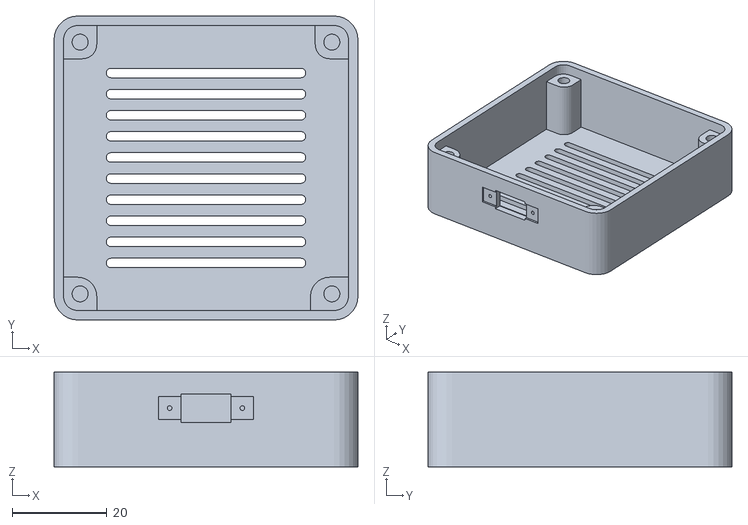
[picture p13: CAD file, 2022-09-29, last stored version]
hardware/Enclosure-DNS-DriveBy/body-v1.1.stl
64.0 x 64.0 x 20.0

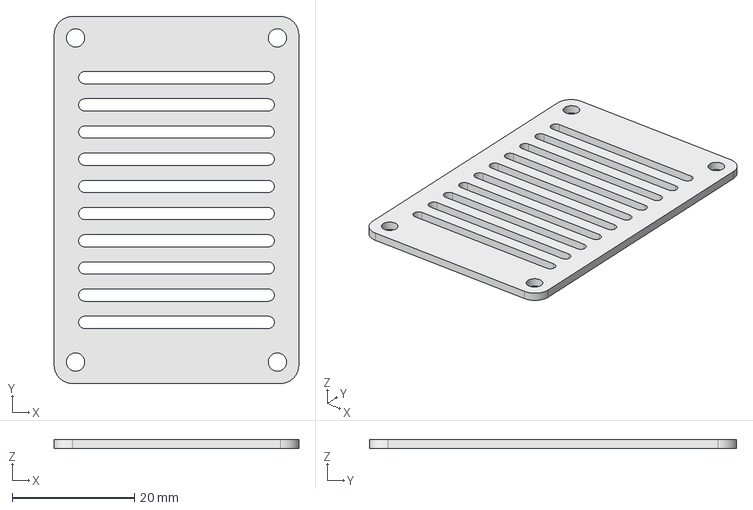
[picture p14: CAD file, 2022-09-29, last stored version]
hardware/Enclosure-DNS-DriveBy/ESP01-lid-v1.FCStd
40.0 x 60.0 x 1.50 mm

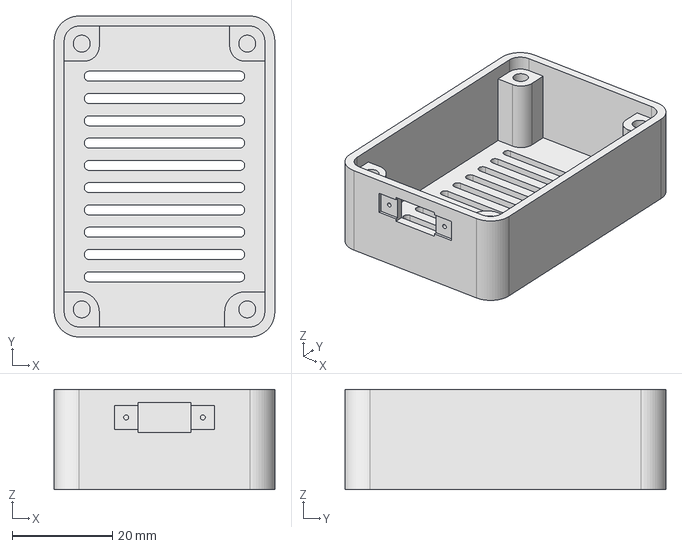
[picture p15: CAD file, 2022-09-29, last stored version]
hardware/Enclosure-DNS-DriveBy/ESP01-body-v1.FCStd
44.0 x 64.0 x 20.0 mm

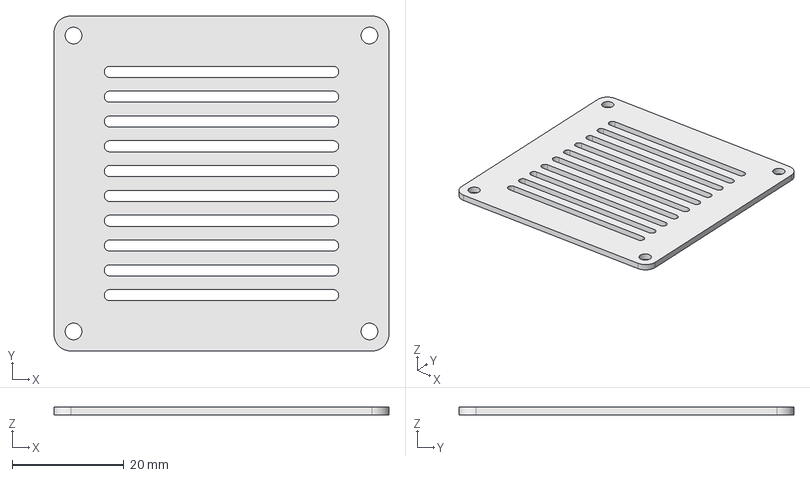
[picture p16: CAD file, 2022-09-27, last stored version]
hardware/Enclosure-DNS-DriveBy/lid-v1.FCStd
60.0 x 60.0 x 1.50 mm

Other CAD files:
hardware/PCB-DNS-DriveBy/art/pcb-outline.FCStd
board-outline.FCStd
hardware/Enclosure-DNS-DriveBy/PCB-Enclosure-Slim.FCStd
hardware/Enclosure-DNS-DriveBy/ENCLOSURE.FCStd
hardware/Enclosure-DNS-DriveBy/board-outline.FCStd
hardware/Enclosure-DNS-DriveBy/body-v1.FCStd
hardware/Enclosure-DNS-DriveBy/body-v1.stl
hardware/Enclosure-DNS-DriveBy/esp-01-lid-v1.stl
hardware/Enclosure-DNS-DriveBy/esp01-body-v1.stl
hardware/Enclosure-DNS-DriveBy/lid-v1.stl
hardware/body-v1.stl
hardware/esp-01-lid-v1.stl
hardware/esp01-body-v1.stl
hardware/lid-v1.stl
hardware/src/enclosure/body-v1.FCStd

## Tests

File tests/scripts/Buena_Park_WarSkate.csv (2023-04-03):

MAC | SSID | Encryption | Datetime | Channel | RSSI | Latitude | Longitude | AltitudeMeters | AccuracyMeters | Type
E0:22:02:08:C3:AE | ATT5ufa9xX | WPA2 | 2023-03-17 22:38:41 | 1 | -66 | 33.859915 | -117.99684 | 79 | 152 | WIFI
F8:A2:6D:93:94:BB | CP1300-9394BB | WPA2 | 2023-03-17 22:38:41 | 1 | -81 | 33.859915 | -117.99684 | 79 | 152 | WIFI
74:85:C4:78:F0:E6 | H3C_78F0E4 | AUTO | 2023-03-17 22:38:41 | 1 | -84 | 33.859915 | -117.99684 | 79 | 152 | WIFI
10:93:97:27:27:50 | Amuse_2.4GHz | WPA2 | 2023-03-17 22:38:41 | 2 | -59 | 33.859915 | -117.99684 | 79 | 152 | WIFI
12:93:97:27:27:51 | Amuse_Guest | WPA2 | 2023-03-17 22:38:41 | 2 | -61 | 33.859915 | -117.99684 | 79 | 152 | WIFI
6C:CD:D6:44:36:D7 | mobileland | WPA2 | 2023-03-17 22:38:41 | 2 | -72 | 33.859915 | -117.99684 | 79 | 152 | WIFI
2C:00:AB:64:7E:10 | ATTTS8BMS2 | WPA2 | 2023-03-17 22:38:41 | 3 | -79 | 33.859915 | -117.99684 | 79 | 152 | WIFI
C0:25:E9:5E:CA:74 | TP-LINK_CA74 | WPA2 | 2023-03-17 22:38:41 | 4 | -77 | 33.859915 | -117.99684 | 79 | 152 | WIFI
80:CC:9C:32:78:DC | ORBI10 | WPA2 | 2023-03-17 22:38:41 | 4 | -78 | 33.859915 | -117.99684 | 79 | 152 | WIFI
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

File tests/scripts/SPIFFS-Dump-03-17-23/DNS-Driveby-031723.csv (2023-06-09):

SSID | Encryption | Datetime | Channel | RSSI | Latitude | Longitude
ATT5ufa9xX | WPA2 | 2023-03-17 22:38:41 | 1 | -66 | 33.859915 | -117.99684
CP1300-9394BB | WPA2 | 2023-03-17 22:38:41 | 1 | -81 | 33.859915 | -117.99684
H3C_78F0E4 | AUTO | 2023-03-17 22:38:41 | 1 | -84 | 33.859915 | -117.99684
Amuse_2.4GHz | WPA2 | 2023-03-17 22:38:41 | 2 | -59 | 33.859915 | -117.99684
Amuse_Guest | WPA2 | 2023-03-17 22:38:41 | 2 | -61 | 33.859915 | -117.99684
mobileland | WPA2 | 2023-03-17 22:38:41 | 2 | -72 | 33.859915 | -117.99684
ATTTS8BMS2 | WPA2 | 2023-03-17 22:38:41 | 3 | -79 | 33.859915 | -117.99684
TP-LINK_CA74 | WPA2 | 2023-03-17 22:38:41 | 4 | -77 | 33.859915 | -117.99684
ORBI10 | WPA2 | 2023-03-17 22:38:41 | 4 | -78 | 33.859915 | -117.99684
DIRECT-41-HP OfficeJet Pro 9010 | NONE | 2023-03-17 22:38:41 | 4 | -78 | 33.859915 | -117.99684
BlueLab | WPA2 | 2023-03-17 22:38:41 | 6 | -76 | 33.859915 | -117.99684
Marko’s iPhone | WPA2 | 2023-03-17 22:38:41 | 6 | -81 | 33.859915 | -117.99684
Desk1 | WPA2 | 2023-03-17 22:38:41 | 1 | -82 | 33.859915 | -117.99684
LeBorn 2.4 | WPA2 | 2023-03-17 22:38:41 | 8 | -83 | 33.859915 | -117.99684
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

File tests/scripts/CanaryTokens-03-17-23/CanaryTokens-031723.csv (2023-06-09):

Timestamp | src_ip | src_data | geo_info | is_tor_relay | input_channel
2023-03-17 22:34:49.1679092489 | 208.54.21.194 | {} | {'loc': '34.0522,-118.2437', 'org': 'AS21928 T-Mobile USA, Inc.', 'city': 'Los Angeles', 'ip': '208.54.21.194', 'region': 'California', 'country': 'US', 'timezone': 'America/Los_Angeles', 'postal': '90009', 'asn': {'route': '208.54.0.0/17', 'type': 'isp', 'asn': 'AS21928', 'domain': 't-mobile.com', 'name': 'T-Mobile USA, Inc.'}} | False | DNS
2023-03-17 22:39:00.1679092740 | 208.54.21.92 | {'generic_data': 'WPA2,-47,Bing Bong'} | {'loc': '34.0522,-118.2437', 'city': 'Los Angeles', 'ip': '208.54.21.92', 'region': 'California', 'timezone': 'America/Los_Angeles', 'country': 'US', 'org': 'AS21928 T-Mobile USA, Inc.', 'postal': '90009', 'asn': {'route': '208.54.0.0/17', 'type': 'isp', 'asn': 'AS21928', 'domain': 't-mobile.com', 'name': 'T-Mobile USA, Inc.'}} | False | DNS
2023-03-17 22:39:01.1679092741 | 208.54.21.194 | {} | {'loc': '34.0522,-118.2437', 'city': 'Los Angeles', 'ip': '208.54.21.194', 'region': 'California', 'timezone': 'America/Los_Angeles', 'country': 'US', 'org': 'AS21928 T-Mobile USA, Inc.', 'postal': '90009', 'asn': {'route': '208.54.0.0/17', 'type': 'isp', 'asn': 'AS21928', 'domain': 't-mobile.com', 'name': 'T-Mobile USA, Inc.'}} | False | DNS
2023-03-17 22:51:14.1679093474 | 208.54.144.209 | {'generic_data': 'WPA2,-67,kpop1'} | {'loc': '47.6564,-122.3048', 'org': 'AS21928 T-Mobile USA, Inc.', 'city': 'Seattle', 'ip': '208.54.144.209', 'region': 'Washington', 'country': 'US', 'timezone': 'America/Los_Angeles', 'postal': '98195', 'asn': {'route': '208.54.144.0/20', 'type': 'isp', 'asn': 'AS21928', 'domain': 't-mobile.com', 'name': 'T-Mobile USA, Inc.'}} | False | DNS
2023-03-17 22:51:15.1679093475 | 208.54.21.92 | {'generic_data': 'WPA2,-67,kpop1'} | {'loc': '34.0522,-118.2437', 'org': 'AS21928 T-Mobile USA, Inc.', 'city': 'Los Angeles', 'ip': '208.54.21.92', 'region': 'California', 'country': 'US', 'timezone': 'America/Los_Angeles', 'postal': '90009', 'asn': {'route': '208.54.0.0/17', 'type': 'isp', 'asn': 'AS21928', 'domain': 't-mobile.com', 'name': 'T-Mobile USA, Inc.'}} | False | DNS
2023-03-17 22:51:16.1679093476 | 208.54.144.220 | {'generic_data': '0033.85931,-117.99755,03/17/23-22:51:07'} | {'loc': '47.6564,-122.3048', 'city': 'Seattle', 'ip': '208.54.144.220', 'region': 'Washington', 'timezone': 'America/Los_Angeles', 'country': 'US', 'org': 'AS21928 T-Mobile USA, Inc.', 'postal': '98195', 'asn': {'route': '208.54.144.0/20', 'type': 'isp', 'asn': 'AS21928', 'domain': 't-mobile.com', 'name': 'T-Mobile USA, Inc.'}} | False | DNS
2023-03-17 22:51:48.1679093508 | 151.164.110.175 | {'generic_data': 'WPA2,-82,VR Universe'} | {'loc': '47.6740,-122.1215', 'city': 'Redmond', 'ip': '151.164.110.175', 'region': 'Washington', 'timezone': 'America/Los_Angeles', 'country': 'US', 'org': 'AS7018 AT&T Services, Inc.', 'postal': '98052', 'asn': {'route': '151.164.0.0/16', 'type': 'isp', 'asn': 'AS7018', 'domain': 'att.com', 'name': 'AT&T Services, Inc.'}} | False | DNS
2023-03-17 22:51:49.1679093509 | 12.121.89.144 | {'generic_data': '0033.85944,-117.99767,03/17/23-22:51:38'} | {'loc': '34.0522,-118.2437', 'org': 'AS7018 AT&T Services, Inc.', 'city': 'Los Angeles', 'ip': '12.121.89.144', 'region': 'California', 'country': 'US', 'timezone': 'America/Los_Angeles', 'postal': '90009', 'asn': {'route': '12.0.0.0/9', 'type': 'isp', 'asn': 'AS7018', 'domain': 'att.com', 'name': 'AT&T Services, Inc.'}} | False | DNS
2023-03-17 22:51:52.1679093512 | 12.121.113.207 | {'generic_data': 'WPA2,-82,VR Universe'} | {'loc': '37.3394,-121.8950', 'city': 'San Jose', 'ip': '12.121.113.207', 'region': 'California', 'timezone': 'America/Los_Angeles', 'country': 'US', 'org': 'AS7018 AT&T Services, Inc.', 'postal': '95103', 'asn': {'route': '12.0.0.0/9', 'type': 'isp', 'asn': 'AS7018', 'domain': 'att.com', 'name': 'AT&T Services, Inc.'}} | False | DNS
2023-03-17 22:55:26.1679093726 | 204.194.237.208 | {'generic_data': 'WPA2,-82,Pizza Hut Guest Wifi'} | {'loc': '34.0522,-118.2437', 'org': 'AS36692 Cisco OpenDNS, LLC', 'city': 'Los Angeles', 'country': 'US', 'region': 'California', 'hostname': 'r2.lax.compute.lax1.edc.strln.net', 'ip': '204.194.237.208', 'timezone': 'America/Los_Angeles', 'postal': '90009', 'asn': {'route': '204.194.237.0/24', 'type': 'isp', 'asn': 'AS36692', 'domain': 'opendns.com', 'name': 'Cisco OpenDNS, LLC'}} | False | DNS
2023-03-17 22:55:27.1679093727 | 204.194.237.208 | {'generic_data': '0033.86100,-117.99812,03/17/23-22:55:19'} | {'loc': '34.0522,-118.2437', 'org': 'AS36692 Cisco OpenDNS, LLC', 'city': 'Los Angeles', 'country': 'US', 'region': 'California', 'hostname': 'r2.lax.compute.lax1.edc.strln.net', 'ip': '204.194.237.208', 'timezone': 'America/Los_Angeles', 'postal': '90009', 'asn': {'route': '204.194.237.0/24', 'type': 'isp', 'asn': 'AS36692', 'domain': 'opendns.com', 'name': 'Cisco OpenDNS, LLC'}} | False | DNS
2023-03-17 22:59:35.1679093975 | 172.69.32.43 | {} | {'loc': '34.0522,-118.2437', 'org': 'AS13335 Cloudflare, Inc.', 'city': 'Los Angeles', 'ip': '172.69.32.43', 'region': 'California', 'country': 'US', 'timezone': 'America/Los_Angeles', 'postal': '90009', 'asn': {'route': '172.69.32.0/24', 'type': 'hosting', 'asn': 'AS13335', 'domain': 'cloudflare.com', 'name': 'Cloudflare, Inc.'}} | False | DNS
2023-03-17 22:59:36.1679093976 | 172.69.32.121 | {} | {'loc': '34.0522,-118.2437', 'city': 'Los Angeles', 'ip': '172.69.32.121', 'region': 'California', 'timezone': 'America/Los_Angeles', 'country': 'US', 'org': 'AS13335 Cloudflare, Inc.', 'postal': '90009', 'asn': {'route': '172.69.32.0/24', 'type': 'hosting', 'asn': 'AS13335', 'domain': 'cloudflare.com', 'name': 'Cloudflare, Inc.'}} | False | DNS
2023-03-17 23:07:34.1679094454 | 172.253.0.1 | {'generic_data': "AUTO,-81,Carl's Jr. Guest WiFi"} | {'loc': '34.0522,-118.2437', 'org': 'AS15169 Google LLC', 'city': 'Los Angeles', 'ip': '172.253.0.1', 'region': 'California', 'country': 'US', 'timezone': 'America/Los_Angeles', 'postal': '90009', 'asn': {'route': '172.253.0.0/16', 'type': 'hosting', 'asn': 'AS15169', 'domain': 'google.com', 'name': 'Google LLC'}} | False | DNS
2023-03-17 23:07:35.1679094455 | 172.253.9.197 | {'generic_data': '0033.87263,-117.99809,03/17/23-23:07:28'} | {'loc': '34.0522,-118.2437', 'city': 'Los Angeles', 'ip': '172.253.9.197', 'region': 'California', 'timezone': 'America/Los_Angeles', 'country': 'US', 'org': 'AS15169 Google LLC', 'postal': '90009', 'asn': {'route': '172.253.0.0/16', 'type': 'hosting', 'asn': 'AS15169', 'domain': 'google.com', 'name': 'Google LLC'}} | False | DNS
2023-03-17 23:08:06.1679094486 | 172.253.0.3 | {'generic_data': "NONE,-81,Carl's Jr. Guest WiFi"} | {'loc': '34.0522,-118.2437', 'city': 'Los Angeles', 'ip': '172.253.0.3', 'region': 'California', 'timezone': 'America/Los_Angeles', 'country': 'US', 'org': 'AS15169 Google LLC', 'postal': '90009', 'asn': {'route': '172.253.0.0/16', 'type': 'hosting', 'asn': 'AS15169', 'domain': 'google.com', 'name': 'Google LLC'}} | False | DNS
2023-03-17 23:08:07.1679094487 | 74.125.181.130 | {'generic_data': '0033.87325,-117.99810,03/17/23-23:08:01'} | {'loc': '34.0522,-118.2437', 'org': 'AS15169 Google LLC', 'city': 'Los Angeles', 'ip': '74.125.181.130', 'region': 'California', 'country': 'US', 'timezone': 'America/Los_Angeles', 'postal': '90009', 'asn': {'route': '74.125.176.0/20', 'type': 'hosting', 'asn': 'AS15169', 'domain': 'google.com', 'name': 'Google LLC'}} | False | DNS
2023-03-17 23:08:17.1679094497 | 66.75.177.5 | {'generic_data': 'NONE,-65,Spectrum Free Trial'} | {'loc': '34.0298,-118.3528', 'org': 'AS20001 Charter Communications Inc', 'city': 'Los Angeles', 'country': 'US', 'region': 'California', 'hostname': 'lsaica-dns-cac-302.socal.rr.com', 'ip': '66.75.177.5', 'timezone': 'America/Los_Angeles', 'postal': '90016', 'asn': {'route': '66.75.0.0/16', 'type': 'isp', 'asn': 'AS20001', 'domain': 'charter.com', 'name': 'Charter Communications Inc'}} | False | DNS
2023-03-17 23:08:18.1679094498 | 66.75.177.6 | {'generic_data': '0033.87327,-117.99811,03/17/23-23:08:09'} | {'loc': '34.0298,-118.3528', 'org': 'AS20001 Charter Communications Inc', 'city': 'Los Angeles', 'country': 'US', 'region': 'California', 'hostname': 'lsaica-dns-cac-303.socal.rr.com', 'ip': '66.75.177.6', 'timezone': 'America/Los_Angeles', 'postal': '90016', 'asn': {'route': '66.75.0.0/16', 'type': 'isp', 'asn': 'AS20001', 'domain': 'charter.com', 'name': 'Charter Communications Inc'}} | False | DNS
2023-03-17 23:08:28.1679094508 | 172.253.2.2 | {'generic_data': "NONE,-69,Carl's Jr. Guest WiFi"} | {'loc': '34.0522,-118.2437', 'org': 'AS15169 Google LLC', 'city': 'Los Angeles', 'ip': '172.253.2.2', 'region': 'California', 'country': 'US', 'timezone': 'America/Los_Angeles', 'postal': '90009', 'asn': {'route': '172.253.0.0/16', 'type': 'hosting', 'asn': 'AS15169', 'domain': 'google.com', 'name': 'Google LLC'}} | False | DNS
2023-03-17 23:08:29.1679094509 | 172.253.0.5 | {'generic_data': '0033.87329,-117.99811,03/17/23-23:08:23'} | {'loc': '34.0522,-118.2437', 'org': 'AS15169 Google LLC', 'city': 'Los Angeles', 'ip': '172.253.0.5', 'region': 'California', 'country': 'US', 'timezone': 'America/Los_Angeles', 'postal': '90009', 'asn': {'route': '172.253.0.0/16', 'type': 'hosting', 'asn': 'AS15169', 'domain': 'google.com', 'name': 'Google LLC'}} | False | DNS
2023-03-17 23:08:49.1679094529 | 172.253.9.196 | {'generic_data': "WPA2,-86,Carl's Jr. Guest WiFi"} | {'loc': '34.0522,-118.2437', 'city': 'Los Angeles', 'ip': '172.253.9.196', 'region': 'California', 'timezone': 'America/Los_Angeles', 'country': 'US', 'org': 'AS15169 Google LLC', 'postal': '90009', 'asn': {'route': '172.253.0.0/16', 'type': 'hosting', 'asn': 'AS15169', 'domain': 'google.com', 'name': 'Google LLC'}} | False | DNS
2023-03-17 23:08:50.1679094530 | 172.253.9.196 | {'generic_data': '0033.87330,-117.99812,03/17/23-23:08:44'} | {'loc': '34.0522,-118.2437', 'org': 'AS15169 Google LLC', 'city': 'Los Angeles', 'ip': '172.253.9.196', 'region': 'California', 'country': 'US', 'timezone': 'America/Los_Angeles', 'postal': '90009', 'asn': {'route': '172.253.0.0/16', 'type': 'hosting', 'asn': 'AS15169', 'domain': 'google.com', 'name': 'Google LLC'}} | False | DNS
2023-03-17 23:08:59.1679094539 | 66.75.177.12 | {'generic_data': 'WPA2,-83,Spectrum Free Trial'} | {'loc': '34.0298,-118.3528', 'city': 'Los Angeles', 'country': 'US', 'region': 'California', 'hostname': 'lsaica-dns-cac-309.socal.rr.com', 'timezone': 'America/Los_Angeles', 'ip': '66.75.177.12', 'org': 'AS20001 Charter Communications Inc', 'postal': '90016', 'asn': {'route': '66.75.0.0/16', 'type': 'isp', 'asn': 'AS20001', 'domain': 'charter.com', 'name': 'Charter Communications Inc'}} | False | DNS
2023-03-17 23:09:00.1679094540 | 66.75.177.12 | {'generic_data': '0033.87331,-117.99813,03/17/23-23:08:52'} | {'loc': '34.0298,-118.3528', 'org': 'AS20001 Charter Communications Inc', 'city': 'Los Angeles', 'country': 'US', 'region': 'California', 'hostname': 'lsaica-dns-cac-309.socal.rr.com', 'ip': '66.75.177.12', 'timezone': 'America/Los_Angeles', 'postal': '90016', 'asn': {'route': '66.75.0.0/16', 'type': 'isp', 'asn': 'AS20001', 'domain': 'charter.com', 'name': 'Charter Communications Inc'}} | False | DNS
2023-03-17 23:09:01.1679094541 | 66.75.177.8 | {'generic_data': '0033.87331,-117.99813,03/17/23-23:08:52'} | {'loc': '34.0298,-118.3528', 'city': 'Los Angeles', 'country': 'US', 'region': 'California', 'hostname': 'lsaica-dns-cac-305.socal.rr.com', 'timezone': 'America/Los_Angeles', 'ip': '66.75.177.8', 'org': 'AS20001 Charter Communications Inc', 'postal': '90016', 'asn': {'route': '66.75.0.0/16', 'type': 'isp', 'asn': 'AS20001', 'domain': 'charter.com', 'name': 'Charter Communications Inc'}} | False | DNS
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

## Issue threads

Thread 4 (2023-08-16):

Make file has a large error in the middle and DNS driveby device doesn't appear to be working

emilyboda, 2023-08-16:
Make file doesn't seem to be compiling properly. There is a large error in the middle of it. I've removed the first line because that's where my canary token was.

```
/dev/ttyUSB0
docker build . --file Dockerfile --tag dnsdriveby
Sending build context to Docker daemon  6.028MB
Step 1/13 : FROM debian:buster
 ---> 1df4474660a1
Step 2/13 : WORKDIR /app
 ---> Using cache
 ---> 3af0c3010f0f
Step 3/13 : RUN apt-get update && apt-get install -y     wget     zip     bsdmainutils     xz-utils     python3 python3-pip
 ---> Using cache
 ---> f7580d533307
Step 4/13 : RUN pip3 install pyserial esptool
 ---> Using cache
 ---> 368dbff43fa9
Step 5/13 : ARG ARDUINO_CLI_VERSION=0.22.0
 ---> Using cache
 ---> cefe3101a8a5
Step 6/13 : RUN wget https://github.com/arduino/arduino-cli/releases/download/${ARDUINO_CLI_VERSION}/arduino-cli_${ARDUINO_CLI_VERSION}_Linux_64bit.tar.gz
 ---> Using cache
 ---> 5e428f1e8f7c
Step 7/13 : RUN tar -xf arduino-cli_${ARDUINO_CLI_VERSION}_Linux_64bit.tar.gz
 ---> Using cache
 ---> 9a8a94be1593
Step 8/13 : COPY arduino-cli.yaml .
 ---> Using cache
 ---> ac22cffd6da0
Step 9/13 : RUN ./arduino-cli core update-index --config-file arduino-cli.yaml
 ---> Using cache
 ---> 9dadae9f6389
Step 10/13 : RUN ./arduino-cli core install esp8266:esp8266
 ---> Using cache
 ---> 9bee0dacb8a9
Step 11/13 : RUN ./arduino-cli lib install     "ESP8266 and ESP32 OLED driver for SSD1306 displays"     "Adafruit NeoPixel"     "TinyGPSPlus"
 ---> Using cache
 ---> 86081f71a674
Step 12/13 : COPY Demo ./Demo
 ---> Using cache
 ---> a2349dab70b3
Step 13/13 : RUN ./arduino-cli compile -b esp8266:esp8266:d1_mini Demo
 ---> Running in 7c24961c92c5
In file included from /app/Demo/Demo.ino:4:
/app/Demo/Scan.h: In function 'uint8_t initGPS()':                                                                                
/app/Demo/Scan.h:46:20: warning: ISO C++ forbids converting a string constant to 'char*' [-Wwrite-strings]                        
   46 |         drawMockup("...","...",0,0,0,0,"Waiting for GPS ...");                                                            
      |                    ^~~~~                                                                                                  
/app/Demo/Scan.h:46:26: warning: ISO C++ forbids converting a string constant to 'char*' [-Wwrite-strings]                        
   46 |         drawMockup("...","...",0,0,0,0,"Waiting for GPS ...");                                                            
      |                          ^~~~~                                                                                            
/app/Demo/Scan.h:46:40: warning: ISO C++ forbids converting a string constant to 'char*' [-Wwrite-strings]                        
   46 |         drawMockup("...","...",0,0,0,0,"Waiting for GPS ...");                                                            
      |                                        ^~~~~~~~~~~~~~~~~~~~~                                                              
In file included from /app/Demo/Demo.ino:4:                                                                                       
/app/Demo/Scan.h:66:59: warning: ISO C++ forbids converting a string constant to 'char*' [-Wwrite-strings]                        
   66 |         drawMockup(currentGPS,currTime,sats,nets,reqs,opn,"GPS SUCCESS");                                                 
      |                                                           ^~~~~~~~~~~~~                                                   
/app/Demo/Scan.h:69:16: warning: ISO C++ forbids converting a string constant to 'char*' [-Wwrite-strings]                        
   69 |     drawMockup("...","...",0,0,0,0,"GPS NOT DETECTED");                                                                   
      |                ^~~~~                                                                                                      
/app/Demo/Scan.h:69:22: warning: ISO C++ forbids converting a string constant to 'char*' [-Wwrite-strings]                        
   69 |     drawMockup("...","...",0,0,0,0,"GPS NOT DETECTED");                                                                   
      |                      ^~~~~                                                                                                
/app/Demo/Scan.h:69:36: warning: ISO C++ forbids converting a string constant to 'char*' [-Wwrite-strings]                        
   69 |     drawMockup("...","...",0,0,0,0,"GPS NOT DETECTED");                                                                   
      |                                    ^~~~~~~~~~~~~~~~~~                                                                     
/app/Demo/Scan.h: In function 'bool connectToOpen()':                                                                             
/app/Demo/Scan.h:165:59: warning: ISO C++ forbids converting a string constant to 'char*' [-Wwrite-strings]                       
  165 |         drawMockup(currentGPS,currTime,sats,nets,reqs,opn,"No open nets found :(");                                       
      |                                                           ^~~~~~~~~~~~~~~~~~~~~~~                                         
/app/Demo/Scan.h:170:64: warning: ISO C++ forbids converting a string constant to 'char*' [-Wwrite-strings]                       
  170 |         drawMockup(currentGPS,currTime,sats,nets,reqs,openNets,"Open nets found!");                                       
      |                                                                ^~~~~~~~~~~~~~~~~~                                         
/app/Demo/Scan.h:182:64: warning: ISO C++ forbids converting a string constant to 'char*' [-Wwrite-strings]                       
  182 |         drawMockup(currentGPS,currTime,sats,nets,reqs,openNets,"Attemping to connect...");                                
      |                                                                ^~~~~~~~~~~~~~~~~~~~~~~~~                                  
/app/Demo/Scan.h:193:76: warning: ISO C++ forbids converting a string constant to 'char*' [-Wwrite-strings]                       
  193 |                     drawMockup(currentGPS,currTime,sats,nets,reqs,openNets,"Failed to connect :(");                       
      |                                                                            ^~~~~~~~~~~~~~~~~~~~~~                         
/app/Demo/Scan.h:214:76: warning: ISO C++ forbids converting a string constant to 'char*' [-Wwrite-strings]                       
  214 |                     drawMockup(currentGPS,currTime,sats,nets,reqs,openNets,"CONNECTED TO NET");                           
      |                                                                            ^~~~~~~~~~~~~~~~~~                             
/app/Demo/Scan.h:218:72: warning: ISO C++ forbids converting a string constant to 'char*' [-Wwrite-strings]                       
  218 |                 drawMockup(currentGPS,currTime,sats,nets,reqs,openNets,"COULDN'T CONNECT");                               
      |                                                                        ^~~~~~~~~~~~~~~~~~                                 
/app/Demo/Scan.h: In function 'void encodeB32()':                                                                                 
/app/Demo/Scan.h:237:55: warning: ISO C++ forbids converting a string constant to 'char*' [-Wwrite-strings]                       
  237 |     drawMockup(currentGPS,currTime,sats,nets,reqs,opn,"Making request...");                                               
      |                                                       ^~~~~~~~~~~~~~~~~~~                                                 
/app/Demo/Scan.h: In function 'bool dnsRequest(char*, uint8_t)':                                                                  
/app/Demo/Scan.h:275:115: warning: ISO C++ forbids converting a string constant to 'char*' [-Wwrite-strings]                      
  275 |         if (dnsRequestSuccess) {Serial.println("[+] Success!"); drawMockup(currentGPS,currTime,sats,nets,reqs,opn,"DNS SUCCESS");}
      |                                                                                                                   ^~~~~~~~~~~~~
/app/Demo/Scan.h:276:117: warning: ISO C++ forbids converting a string constant to 'char*' [-Wwrite-strings]                      
  276 |         else                   { Serial.println("[-] Failed :("); drawMockup(currentGPS,currTime,sats,nets,reqs,opn,"DNS FAILED :(");}                                                                                                                              
      |                                                                                                                     ^~~~~~~~~~~~~~~                                                                                                                                 
/app/Demo/Scan.h: In function 'void makeDNSRequest()':                                                                            
/app/Demo/Scan.h:299:63: warning: ISO C++ forbids converting a string constant to 'char*' [-Wwrite-strings]                       
  299 |             drawMockup(currentGPS,currTime,sats,nets,reqs,opn,"DNS FAILED :(");                                           
      |                                                               ^~~~~~~~~~~~~~~                                             
/app/Demo/Scan.h:308:59: warning: ISO C++ forbids converting a string constant to 'char*' [-Wwrite-strings]                       
  308 |         drawMockup(currentGPS,currTime,sats,nets,reqs,opn,"DNS SUCCESS");                                                 
      |                                                           ^~~~~~~~~~~~~                                                   
/app/Demo/Scan.h: In function 'char* getEncryption(uint8_t)':                                                                     
/app/Demo/Scan.h:320:16: warning: ISO C++ forbids converting a string constant to 'char*' [-Wwrite-strings]                       
  320 |         return "WEP"; // WEP                                                                                              
      |                ^~~~~                                                                                                      
/app/Demo/Scan.h:322:16: warning: ISO C++ forbids converting a string constant to 'char*' [-Wwrite-strings]                       
  322 |         return "WPA"; // WPA                                                                                              
      |                ^~~~~                                                                                                      
/app/Demo/Scan.h:324:16: warning: ISO C++ forbids converting a string constant to 'char*' [-Wwrite-strings]                       
  324 |         return "WPA2"; // WPA2                                                                                            
      |                ^~~~~~                                                                                                     
/app/Demo/Scan.h:326:16: warning: ISO C++ forbids converting a string constant to 'char*' [-Wwrite-strings]                       
  326 |         return "NONE"; // NONE                                                                                            
      |                ^~~~~~                                                                                                     
/app/Demo/Scan.h:328:16: warning: ISO C++ forbids converting a string constant to 'char*' [-Wwrite-strings]                       
  328 |         return "AUTO"; // AUTO
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

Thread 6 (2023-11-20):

External Antenna Documentation

r3dfish, 2023-11-20:
I see the 5 hole cutout on the board for an external antenna, which I can see mounted in the following images:

https://lyndlabs.io/cdn/shop/files/dns-driveby-battery.jpg?v=1691353218&width=990
https://lyndlabs.io/cdn/shop/files/dns-driveby-computer.jpg?v=1691353218&width=990

but I don't see any documentation or even mention of the external antenna.  Can you please provide what hardware to use, and where/how to install the antenna?

Thanks

lukeswitz, 2023-11-20:
It's confusing indeed. Ships with an ESP8266 D1 Mini, you **need a D1 Mini Pro** to attach an antenna via UFL > IPEX > SMA.

There's no UFL to attach to on the D1. It's about $15 in parts for the upgrade to the Pro & SMA:
- Get [something like this](https://www.rfsupplier.com/ufl-ufl-ipx-ipex-to-sma-female-thru-holes-jack-right-angle-pcb-mount-rf-coaxial-cable-assembly-113mm-coax_p7390.html) but with 2.0mm not 1.3mm IPEX-
- Solder in place, generously for support.
- Replace the D1 > Pro and flash the image.

Not much to it, and FWIW I run them side-by-side and there is little difference.

AlexLynd, 2023-11-24:
@r3dfish Hey!  I responded to this issue via email but it looks like it bounced.

[I shot some pics & wrote some docs here.](https://dnsdriveby.com/guides/mods/external-antenna/).  Let me know if you have any other questions!  If you want to suggest future documentation, if you could leave an issue on the [docs repo](https://github.com/LyndLabs/dnsdriveby.com/) that'd be awesome :)

If you don't have any other questions, you can close out the issue.  Thanks for supporting the project!

- Alex

Closed 2023-11-24.

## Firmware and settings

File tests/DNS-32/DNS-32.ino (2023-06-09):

// TODO
// Real Time
// Persistent Count Vars
// Handle Overflow?
// Optimize String Dumping / Reading
// More comments
// Makefile params
// Add error logging?
// Use Second Serial port for logging

#include <WiFi.h>
#include <TinyGPS++.h>
#include <TimeLib.h>   
#include <HardwareSerial.h>
#include "FS.h"
#include "ESPFlash.h"
#include "ESPFlashCounter.h"
#include "Queue.h"
#include "Base32.h"

#define CANARYTOKEN_URL "2feyjwh66bfsl8qqrugtfldqo.canarytokens.com"

#define WIFI_LOG_INTERVAL 2
#define MAX_GPS_BUFFER_SIZE 10
#define MAX_GPS_QUEUE_SIZE 50
#define MAX_COUNTER 10000

#define WIFI_DELAY        500
#define MAX_CONNECT_TIME  7000

// SoftwareSerial gpsSerial(2, 0); // RX, TX
HardwareSerial Serial2(2);

TinyGPSPlus tinyGPS;

Base32 base32;

unsigned long pTime = millis(); 

float cGPS[MAX_GPS_BUFFER_SIZE][2];        // lat, long
uint32_t cGPSTime[MAX_GPS_BUFFER_SIZE][2]; // date, time
uint8_t cGPSIndex = 0;

/** DEFINE DATA STRUCTURES & COUNTERS **/

// uint32_t coordsCounter = 0; // how many coords are stored 
// uint32_t dataCounter = 0;   // TOTAL Wi-Fi entries
// uint32_t pushCounter = 0;   // Current Wi-Fi Entry to push

ESPFlashCounter coordsCounter("/cCounter");
ESPFlashCounter dataCounter("/dCounter");
ESPFlashCounter pushCounter("/pCounter");

ESPFlash<float>    gpsLogFile("/gpsCoordFile"); // GPS Coordinates
ESPFlash<uint32_t> gpsTimeFile("/gpsTimeFile"); // DateTime

ESPFlash<uint8_t> wifiCount("wifiCountFile"); // Number of WiFi nets for each GPS entry ^
ESPFlash<char>    reconB32("/reconB32");      // WiFi Nets + Metadata as B32 char arrays
ESPFlash<uint8_t> reconLen("/reconLen");      // Length of each WiFi entry

Queue<char *> gpsQueue = Queue<char *>(MAX_GPS_QUEUE_SIZE*63); // max gps coordinates times 63-byte encoded strings

void setup() {
    // pinMode(1, FUNCTION_3); 
    // pinMode(3, FUNCTION_3); 

    // Serial.begin(9600);
    Serial2.begin(9600,SERIAL_8N1,16,18);
    Serial.begin(9600);

    Serial.println(); 
    Serial.println("*********************");
    Serial.println("Starting DNS DriveBy!");
    Serial.println("dnsdriveby.com | Alex Lynd, 2023");
    Serial.println("*********************");

    delay(500);

  if (Serial.available() > 0) {
    Serial.println("[+][GPS ] Trying to get GPS fix");
    Serial.println("[+][GPS ] ");
  }
  else {
    Serial.println("[-][GPS ] No GPS connected, check wiring.");
    delay(1000);
    ESP.restart();
  }
  while (!tinyGPS.location.isValid()) {
    Serial.print(".");
    delay(0);
    smartDelay(500);
  }

    Serial.println();
    Serial.println("[+][GPS ] Current fix: (" + String(tinyGPS.location.lat(), 5) + "," + String(tinyGPS.location.lng(), 5) + ")");
    Serial.end();

    Serial.print("[ ] Formatting SPIFFS...");
    SPIFFS.begin();
    Serial.println("Finished!");

    if(!SPIFFS.exists("/cCounter")) {
        coordsCounter.set(0);
        dataCounter.set(0);
        pushCounter.set(0);
    }
    Serial.printf("Coords: %d // WiFi: %d // Index: %d\n\r",coordsCounter.get(), dataCounter.get(), pushCounter.get());

    WiFi.softAPdisconnect();
    WiFi.disconnect();
    WiFi.mode(WIFI_STA);
    delay(WIFI_DELAY);
    // Serial.println("[+] Started Wi-Fi STATION Mode!");
}

static void smartDelay(unsigned long ms) {
  unsigned long start = millis();
  do {
    while (Serial.available())
      tinyGPS.encode(Serial.read());
  } while (millis() - start < ms);
}

void initializeGPS() {
 
}

/* -------------------------------------------------------------*/
/* ------------- Log GPS & DateTime Info -> Flash ------------- */
/* -------------------------------------------------------------*/

void logGPSDateTime() {


    /********** GET GPS Data  **********/

    while (!tinyGPS.time.isValid()) { delay(0); }

    float lat = tinyGPS.location.lat();
    float lon = tinyGPS.location.lng();

    uint32_t date = (10000 *tinyGPS.date.month()) + (100*tinyGPS.date.day()) + (getPlaceValue(tinyGPS.date.year(),0));
    uint32_t time = (10000 *tinyGPS.time.hour()) + (100*tinyGPS.time.minute()) + (tinyGPS.time.second());    
    // Serial.printf("%d %d  //  ",lat,lon);

    /**** APPEND to Files in Flash  ****/

    gpsLogFile.append(lat);
    gpsLogFile.append(lon);

    gpsTimeFile.append(date);
    gpsTimeFile.append(time);

}

/* -------------------------------------------------------------*/
/* ------------ Return GPS + DateTime as B32 String ------------*/
/* -------------------------------------------------------------*/

char *getGPSDateTimeB32(uint32_t gpsIndex) {

    float lat = gpsLogFile.getElementAt(2*gpsIndex);
    float lon = gpsLogFile.getElementAt((2*gpsIndex)+1);

    uint32_t date = gpsTimeFile.getElementAt(2*gpsIndex);
    uint32_t time = gpsTimeFile.getElementAt((2*gpsIndex)+1);

    uint8_t mon = getPlaceValue(date, 3); uint8_t day = getPlaceValue(date, 2); uint8_t year = getPlaceValue(date, 1);
    uint8_t hour = getPlaceValue(time, 3); uint8_t min = getPlaceValue(time, 2); uint8_t sec = getPlaceValue(time, 1);

    // FORMAT:  Lat(5),Long(5),MM/DD/YY-HH:MM:SS
    char gpsDateTimeStr[39]; sprintf(gpsDateTimeStr, "%010.5f,%010.5f,%02d/%02d/%02d-%02d:%02d:%02d",lat,lon,mon,day,year,hour,min,sec);
    
    // CONVERT to Base 32
    char *gpsDateTimeB32;         
    base32.toBase32((byte*) gpsDateTimeStr,sizeof(gpsDateTimeStr),(byte*&)gpsDateTimeB32,false);
    return gpsDateTimeB32;
}
/* --------------------------------------------------------------*/
/* --------- Return the nth position value of a number --------- */
/* --------------------------------------------------------------*/

uint8_t getPlaceValue(uint32_t timeInt, uint8_t placeValue) {
    uint32_t placeMultiplier = 1; for(uint8_t i=1; i<placeValue; i++) { placeMultiplier*=100; }
    return uint8_t ((timeInt/(placeMultiplier))%100U);
}

/* --------------------------------------------------------------*/
/* -------- Maps default encryption value to values 0-4 -------- */
/* --------------------------------------------------------------*/

uint8_t getEncryption(uint8_t network) {
  byte encryption = WiFi.encryptionType(network);
  switch (encryption) {
    case 5: 
        return 0; // WEP
    case 2: 
        return 1; // WPA
    case 4: 
        return 2; // WPA2
    case 7: 
        return 3; // NONE
    case 8: 
        return 4; // AUTO
  }
  return 4; // AUTO / fail case
}

/* --------------------------------------------------------------*/
/* Scans & logs WiFi networks & attempts to connect to open nets */
/* --------------------------------------------------------------*/

char ssid[32] = "";
char wifiString[38]; // 32B SSID, 1B Encryption, 3B RSSI

void wifiScan(uint8_t wifiScanInterval) {

    // don't scan unless interval

    memset(ssid, 0, 32);
    uint8_t openNets=0;
    // Serial.print("Scanning networks...");
    int networks = WiFi.scanNetworks(false, false);

    /* ------------------------------------------------ */
    /* ---------- LOG ALL NETWORKS -> FLASH  ---------- */
    /* ------------------------------------------------ */

    if (networks == 0) { /*Serial.println("none found :(");*/ return; }
    else {
        // Serial.printf("%02d found!",networks);

        unsigned long tmpEntTime = millis();
        unsigned long tmpExitTime = millis();

        wifiCount.append(networks);
        for (uint8_t i=0; i<networks; i++) {
            if(WiFi.SSID(i).length() > 0) {

                /********** Plain Text WiFi String  **********/
                sprintf(wifiString,"%d,%d,%.32s",getEncryption(WiFi.encryptionType(i)),WiFi.RSSI(i),WiFi.SSID(i).c_str()); // ENC, RSSI, SSID
                uint8_t lenWifiStr = WiFi.SSID(i).length()+6;

                /********** B32 WiFi String **********/
                char *wifiDataB32;         
                uint8_t lenWiFiDataB32 = base32.toBase32((byte*) wifiString,lenWifiStr,(byte*&)wifiDataB32,false);

                /********** LOG WiFi to Memory  **********/
                // TODO: Check if char* or char[] matters for call back, String for quicker append?

                for(uint8_t i=0; i<lenWiFiDataB32; i++) { reconB32.append(wifiDataB32[i]); }   // LOG WiFi B32 String
                reconLen.append(lenWiFiDataB32);                                               // LOG size of WiFi SSID
                
                // // Serial.printf("(%d): %s\n",lenWiFiDataB32, wifiDataB32);

                delete wifiDataB32;              
                dataCounter.increment();               
            }
            tmpExitTime = millis();
        }
        // // Serial.printf();

        // Serial.printf("  //  Logged in %06d ms  //  Total Nets: %d  //",tmpExitTime-tmpEntTime, dataCounter);
        logGPSDateTime(); // LOG GPS + DateTime Info
        return;
        // Serial.printf("  GPS SUCCESS\n");

        /* ------------------------------------------------ */
        /* ------- CONNECT TO OPEN NETS & PUSH DATA ------- */
        /* ------------------------------------------------ */

        // RETURN if no new data
       if (pushCounter.get() >= dataCounter.get()) { return; } 

        // RETURN if no Open Networks
        int indices[networks];
        // for (int i = 0; i < networks; i++) { indices[i] = i; if(WiFi.encryptionType(indices[i]) == WIFI_AUTH_OPEN) {openNets++;} }
        // if (openNets == 0) { return; }

        // SORT Open Networks by RSSI
        // Serial.print("Open Networks: "); Serial.println(openNets);
        // for (int i = 0; i < networks; i++) {
        //     for (int j = i + 1; j < networks; j++) {
        //         if (WiFi.RSSI(indices[j]) > WiFi.RSSI(indices[i])) { std::swap(indices[i], indices[j]); }
        //     }
        // }

        // CONNECT to Open WiFi Networks
        for (int i = 0; i < networks; i++) {
            if(WiFi.encryptionType(indices[i]) == WIFI_AUTH_OPEN) {
                memset(ssid, 0, 32);
                strncpy(ssid, WiFi.SSID(indices[i]).c_str(), 32);

                WiFi.begin(ssid);
                // Serial.print("[+][WiFi] Connecting to: "); Serial.println(ssid);
                // Serial.print("[+][WiFi] ");

                unsigned long currWiFi = millis();
                unsigned long prevWiFi = millis();

                // if connecting takes longer than threshold
                while (WiFi.status() != WL_CONNECTED and (currWiFi-prevWiFi<MAX_CONNECT_TIME)) {
                    currWiFi = millis();
                    delay(WIFI_DELAY);
                    // Serial.print(".");
                }


                uint8_t dnsReqFails = 0;
                // if connection successful, create DNS requests
                if (WiFi.status() == WL_CONNECTED) {
                    // Serial.println(" connected!");
                    while (WiFi.status() == WL_CONNECTED and pushCounter.get() < dataCounter.get()) {
                        bool dnsRequestSuccess = dnsRequest();
                        dnsReqFails+= !dnsRequestSuccess;
                        if (dnsReqFails > 3) {
                            // Serial.println("Too many failures, disconnecting.");
                            WiFi.disconnect();
                            dnsReqFails = 0;
                            return;
                        }
                    }
                    // Serial.println("Exhausted list.");
                    return;
                }
                else {
                    // Serial.println("[-][WiFi] Can't connect :(");
                    break;
                }
            }
        }
    }

    // Serial.println();
}

/* --------------------------------------------------------------*/
/* Make DNS Request -> CanaryToken & Pop from memory */
/* --------------------------------------------------------------*/


uint32_t indexCurrentToken=0;

uint8_t wifiNetGroup = 0;

bool dnsRequest() {

    bool dnsRequestSuccess;
    // start at index of last pushed
    uint32_t startIndex = pushCounter.get();

        /********** Get WiFi & MetaData as B32 String **********/
        uint8_t lenCurrentWiFiData = reconLen.getElementAt(pushCounter.get());
        char wifiDataB32[61];
        uint8_t counter = 0;
        for (uint32_t j=indexCurrentToken; j<indexCurrentToken+lenCurrentWiFiData; j++) {
            wifiDataB32[counter] = reconB32.getElementAt(j);
            counter++;
        }

        /********** Get DateTime + GPS **********/
        char *gpsB32String = getGPSDateTimeB32(coordsCounter.get());

        /********** MAKE DNS REQUEST **********/
        char  gpsURL[63+2+3+sizeof(CANARYTOKEN_URL)]; // 63B - GPS  B32
        char wifiURL[61+2+3+sizeof(CANARYTOKEN_URL)]; // 61B - WiFi B32

        sprintf(gpsURL,"%.63s.G%d.%s",gpsB32String,random(10,99),CANARYTOKEN_URL);
        dnsRequestSuccess = makeDNSRequest(gpsURL);
        delay(300);

        sprintf(wifiURL,"%.*s.G%d.%s",lenCurrentWiFiData,wifiDataB32,random(10,99),CANARYTOKEN_URL);
        dnsRequestSuccess = makeDNSRequest(wifiURL);

        /********** Keep Track of GPS Coordinates Per Group **********/
        delete gpsB32String;
        wifiNetGroup++;
        if (wifiNetGroup >= wifiCount.getElementAt(coordsCounter.get())) {
            wifiNetGroup =0; coordsCounter.increment();
        }
        
        indexCurrentToken+= lenCurrentWiFiData;
        pushCounter.increment();
        return dnsRequestSuccess;
}

/* --------------------------------------------------------------*/
/*  ----------------- Make DNS Request to URL ------------------ */
/* --------------------------------------------------------------*/

bool makeDNSRequest(char *url) {
    bool success;
    IPAddress resolvedIP;
    if(WiFi.hostByName(url, resolvedIP)) { success = true; }
    else {
        unsigned long currReq = millis();
        unsigned long prevReq = millis();

        while(currReq-prevReq < 3000) {
            success = WiFi.hostByName(url, resolvedIP);
            currReq = millis();
            yield();
        }
    }

    if (success) {Serial.printf("[+] Pushing (%d/%d): Success!\n\r"),pushCounter.get(),dataCounter.get();}
    else         {Serial.printf("[+] Pushing (%d/%d): Failure :(\n\r"),pushCounter.get(),dataCounter.get();}
    
    return success;
}

void loop() {
    wifiScan(WIFI_LOG_INTERVAL);
    smartDelay(500);
}

void printUsage() {
    // FSInfo fs_info;
    // SPIFFS.info(fs_info);
    // Serial.printf("Heap: %d // Flash: (%d/%d)",ESP.getFreeHeap(),fs_info.usedBytes,fs_info.totalBytes);
}

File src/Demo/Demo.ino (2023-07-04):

#define GPSBaud 9600

#include "Log.h"
#include "Scan.h"
#include "Screen.h"

extern TinyGPSPlus tinyGPS;
extern SoftwareSerial ss;
extern SH1106Wire display;

void setup() {
  Serial.begin(115200); printHeader();
  initScreen(D1,D2,0x3C);
  display.init();
  display.flipScreenVertically();
  display.setFont(DejaVu_Sans_Mono_10);
  display.setTextAlignment(TEXT_ALIGN_LEFT);
  display.clear();
  drawSplash(2);
  // initialize GPS
  ss.begin(GPSBaud);
  bool gpsSuccess = initGPS();
  if(!gpsSuccess) {Serial.println("[-] RESTARTING"); delay(500); ESP.reset();}
  delay(500);
  initWiFi();

}

void loop() {
  dnsDriveby();
}

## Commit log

2022-09-26 create electronics enclosure
    [Enclosure.FCStd, Lid.FCStd, board-outline.FCStd]
2022-09-27 create working DNS exfil prototype
2022-09-27 update design to accomodate wider PCB
    [PCB.kicad_pcb, PCB.kicad_sch, body-v1.FCStd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]
2022-09-29 update design files for smaller case
    [ESP01-body-v1.FCStd, ESP01-lid-v1.FCStd, body-v1.1.stl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]
2023-01-18 organize source & hardware files v1.0
    [DNS-DriveBy.kicad_pcb, DNS-DriveBy.kicad_sch, ESP01-body-v1.FCStd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]
2023-01-18 export DNS DriveBy v1.0 files
    [DNS-DriveBy-B_Cu.gbl, DNS-DriveBy-B_Mask.gbs, DNS-DriveBy-B_Paste.gbp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]
2023-01-18 update export format
    [DNS-DriveBy.kicad_pcb]
2023-02-06 implement memory queue & encoding poc
    [DNS-DriveBy.kicad_pcb]
2023-03-04 fix persistent logging bug: int overflow
    [DNS-DriveBy.ino]
2023-04-03 update directories, add SPIFFS dump & control data
    [Buena_Park_WarSkate.csv]
2023-06-09 PCB improvements: screen + serial breakout, re-routeable GPS pins
    [17dkvaupy14m8ya1dgg6315lf_history-1.csv, 17dkvaupy14m8ya1dgg6315lf_history-2.csv, 17dkvaupy14m8ya1dgg6315lf_history-3.csv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]
2023-06-09 update resistor values
    [DNS-DriveBy-B_Cu.gbl, DNS-DriveBy-B_Mask.gbs, DNS-DriveBy-B_Paste.gbp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]
2023-06-09 upload zipped gerber
2023-06-09 add GPS ground jumper bypass
    [DNS-DriveBy-B_Cu.gbl, DNS-DriveBy-B_Mask.gbs, DNS-DriveBy-B_Paste.gbp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]
2023-06-09 update PCB export v1.1
    [DNS-DriveBy.kicad_pcb]
2023-06-15 fix low-power mode hardware, add jumper pads, graphics
    [DNS-DriveBy-B_Cu.gbl, DNS-DriveBy-B_Mask.gbs, DNS-DriveBy-B_Paste.gbp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]
2023-07-05 add automation scripts
    [17dkvaupy14m8ya1dgg6315lf_history-1.csv, 17dkvaupy14m8ya1dgg6315lf_history-2.csv, 17dkvaupy14m8ya1dgg6315lf_history-3.csv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]
2023-11-21 GPS Pins backwards for the board I received
    With the GPS pins configured backwards, initGPS() in Demo.ino never returns true, so the board just resets every ~5 seconds. Swapping the pins to the correct orientation allowed for the GPS board to communicate with the D1 chip.
